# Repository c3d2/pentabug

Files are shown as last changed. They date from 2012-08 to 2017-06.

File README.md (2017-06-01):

pentabug
========

**If you experience difficulties with your bug, please check the [troubleshooting documentation](https://github.com/c3d2/pentabug/blob/master/troubleshooting.md).**

The pentabug is a small microcontroller soldering project. It's especially suited for young hackers and beginners of all ages. Assembly requires no prior soldering skills and can be accomplished - with a little help for the tricky parts - by children old enough to savely hold a soldering iron (thats about 7 years and up).

At various events, e.g. [Datenspuren 2012 and 2013](http://datenspuren.de "Datenspuren 2012 and 2013"), Chaos Communication Congress 2012-2015, and many more, several hundred kits have been successfully assembled with just a handfull of bugs needing 'special treatment' for e.g. a controller mounted the wrong way. Have a look at our [slides in german](/c3d2/pentabug/raw/master/doc/201210_slides_datenspuren.pdf "slides form the Datenspuren 2012 talk") from the accompanying [presentation](http://www.datenspuren.de/2012/fahrplan/events/5074.de.html "pentabug talk announcement") or watch [this video](http://www.youtube.com/watch?v=HTBhXqNR6LY "Dresdner Piratencast Folge 14 - Datenspuren") of Frank and his sons beeing interviewed at our workshop table or the [NDR report](https://www.ndr.de/fernsehen/sendungen/hamburg_journal/Kleine-Hacker-am-Werk,hamj45298.html) covering the 32c3 Junghackertag.

A complete walktrough of the assembly process is given in ["Pentabug - The Movie"](http://www.c3d2.de/news/video-pentabug-bauen.html "Pentabug - The Movie"), courtesy of [C3D2 - Chaos Computer Club Dresden](http://c3d2.de "C3D2 - Chaos Computer Club Dresden"). It would be amazing if Scott Manley could do an english version ;-). I would even visit SF to make that happen. 

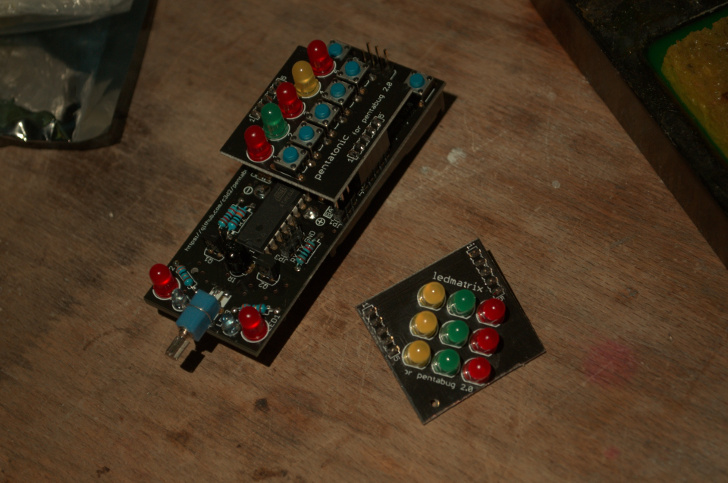
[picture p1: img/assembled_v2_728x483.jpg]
Assembled V2 PCB with extension boards
  
Img. 1: A completely assembled V2 PCB with extension boards.

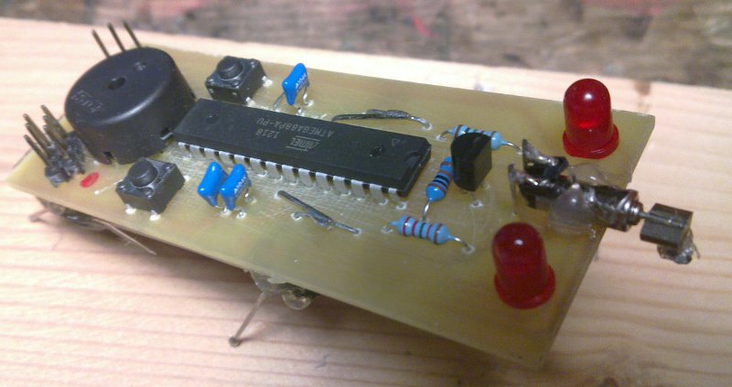
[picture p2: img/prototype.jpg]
Slightly Advanced Prototype Hardware
  
Img. 2: A slightly advanced (but early) prototype version of the bug with a single layer pcb.

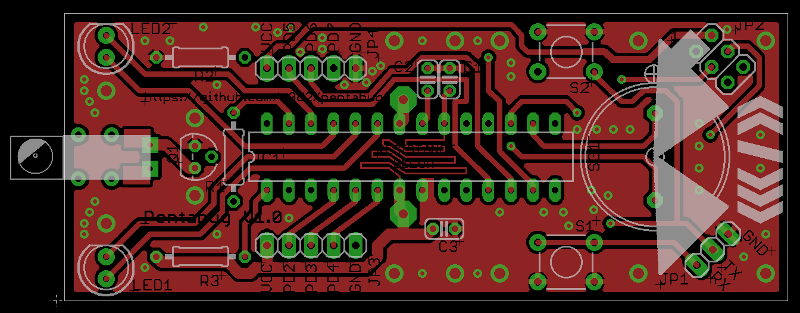
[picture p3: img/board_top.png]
Top Layer of Version 1.0 Board
  
Img. 3: The top layer view of the Version 1.0 production board (two layer pcb).

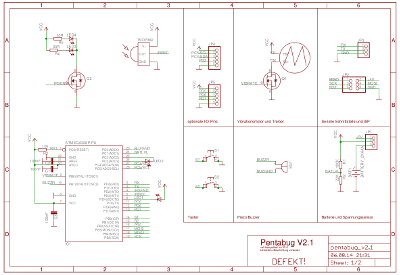
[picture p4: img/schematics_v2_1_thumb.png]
Version 2.1 Schematics (Thumbnail)
  
Img. 4: Version 2.1 schematics ([high resolution image](https://github.com/c3d2/pentabug/raw/master/img/schematics_v2_1.png "high resolution image of schematics")).

[Bill of Materials for Version 1.0](https://github.com/c3d2/pentabug/blob/master/bom.md "bill of materials") - CAVE: This is outdated for the V2.0 and V2.1 versions.

Programming
===========

A quite comprehensive documentation in German for setting up the development toolchain is available at [RHOIO's Blog](https://rhoio.wordpress.com/2014/02/06/den-pentabug-programmieren/).

AVR GCC Toolchain
------------------

 * install binutils-avr, gcc-avr, avr-libc, avrdude
 <pre><code>sudo apt-get install binutils-avr gcc-avr avr-libc avrdude</code></pre>

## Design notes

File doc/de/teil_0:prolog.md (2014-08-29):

# RTFM: Pentabug

## Vorwort

Lieber Junghacker-Padawan,

dies ist die Dokumentation zum [Pentabug-Projekt](https://github.com/c3d2/pentabug).

Wenn Du sie liest und verinnerlichst, wirst Du Deinen Pentabug von innen bis
aussen kennen. Du wirst wissen, wie er entstanden ist, wie er aufgebaut ist,
welche Fähigkeiten er besitzt und wie Du ihn erweitern kannst.

Doch viel mehr wirst Du selbst gelernt haben, ein Projekt wie den Pentabug zu
realisieren. Du wirst zum Junghacker-Jedi.

## Struktur dieser Dokumentation

Diese Dokumentation ist in verschiedene Teile aufgebaut.
Wir fangen ganz von vorne an und gehen bis ganz zum Ende. 
Danach gehen wir noch weiter nach vorne und enden noch weiter hinten.

So kommst Du ganz ohne Basiswissen schnell zu ergebnissen und brauchst nur
jeweils so viel lesen, wie Dich interessiert.

Teil 1: [Episode 2 - Das Gelöt von Pentabug](teil_1:episode_2.md)  
Teil 2: Episode 3 - Mögen die Bits mit Dir sein  
Teil 3: Episode 1 - Layout und Ätzen  

# Teil 1: [Episode 2 - Das Gelöt von Pentabug](teil_1:episode_2.md)  

Inhalt soll werden: 
 - Funktionen des Pentabug 
 - Wie findet man den richtigen Lötkolben
 - Wie lötet man richtig.
 - Was machtjedes Bauteil

# Teil 2: Episode 3 - Mögen die Bits mit Dir sein  TODO
# Teil 3: Episode 1 - Layout und Ätzen TODO

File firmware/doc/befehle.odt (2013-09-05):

#include <pentabug/hal.h>

led_on(seite) | Macht die LED auf einer Seite an
led_off(seite) | Macht die LED auf einer Seite aus
led_inv(seite) | Wechselt ob LED an oder aus ist
led_set(seite, an) | Macht LED aus wenn zweiter Parameter 0 ist, sonst an
led_state(seite) | Gibt zurück ob LED an ist
motor_on() | Macht Motor an
motor_off() | Macht Motor aus
motor_inv() | Wechselt ob Motor an oder aus ist
motor_set() | Macht Motor aus wenn Parameter 0 ist, sonst an
button_clicked(seite) | Gibt zurück ob der Button gedrückt wurde
ir_on() | Sendet Infrarot Signal
ir_off() | Schaltet Infrarot Signal aus
ir_inv() | Wechselt ob Infrarot Signal gesendet wird
ir_set() | Macht IR Signal aus wenn 0, sonst sendet es
ir_recv() | Gibt 1 zurück wenn Signal empfangen wird, sonst 0
wait_ms(ms) | Wartet die gegebene Anzahl an Millisekunden (kleiner als 1.5s!)

#include <pentabug/music.h>

set_note(note, oktave) | Spielt den entsprechenden Ton
stop_note() | Stoppt die Wiedergabe von Tönen

#include <pentabug/photons.h>

photons_init() | Initialisiert Lichtmessung
photons_stop() | Stoppt die Lichtmessung
photons_measure() | Gibt zurück wieviel Licht gemessen wurde (0-256)

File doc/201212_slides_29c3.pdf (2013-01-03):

pentabug | pentarm13uxx | outtro

## pentabug and pentarm13uxx

unadulterated fun with microcontrollers (for everyone)

bigalex, sebseb7

pentabug - beep. rattle. narf.

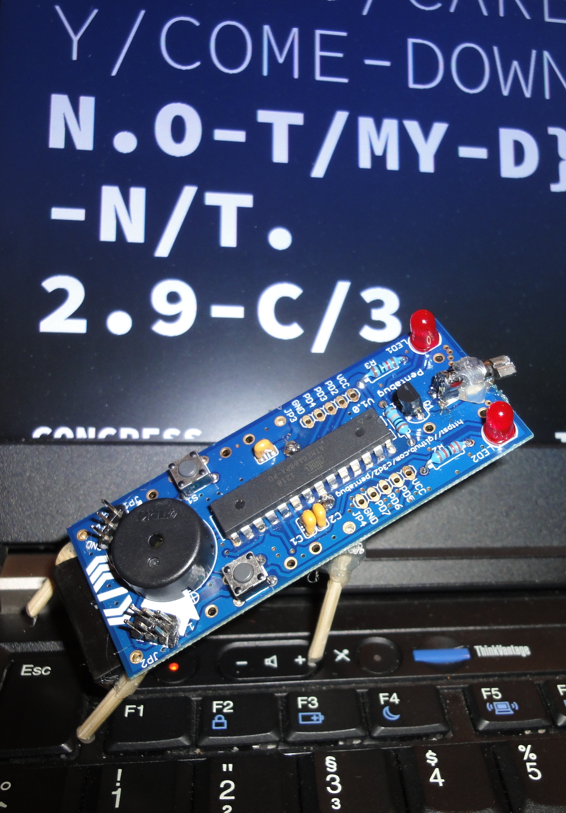
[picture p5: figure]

I battery powered ATmega88P I LEDs, switches
I piezo buzzer, vibration motor I ISP, USART
I extension connectors
I entry level project for beginners
I 100 bugs built at Datenspuren 2012

## Being n1ce to novices

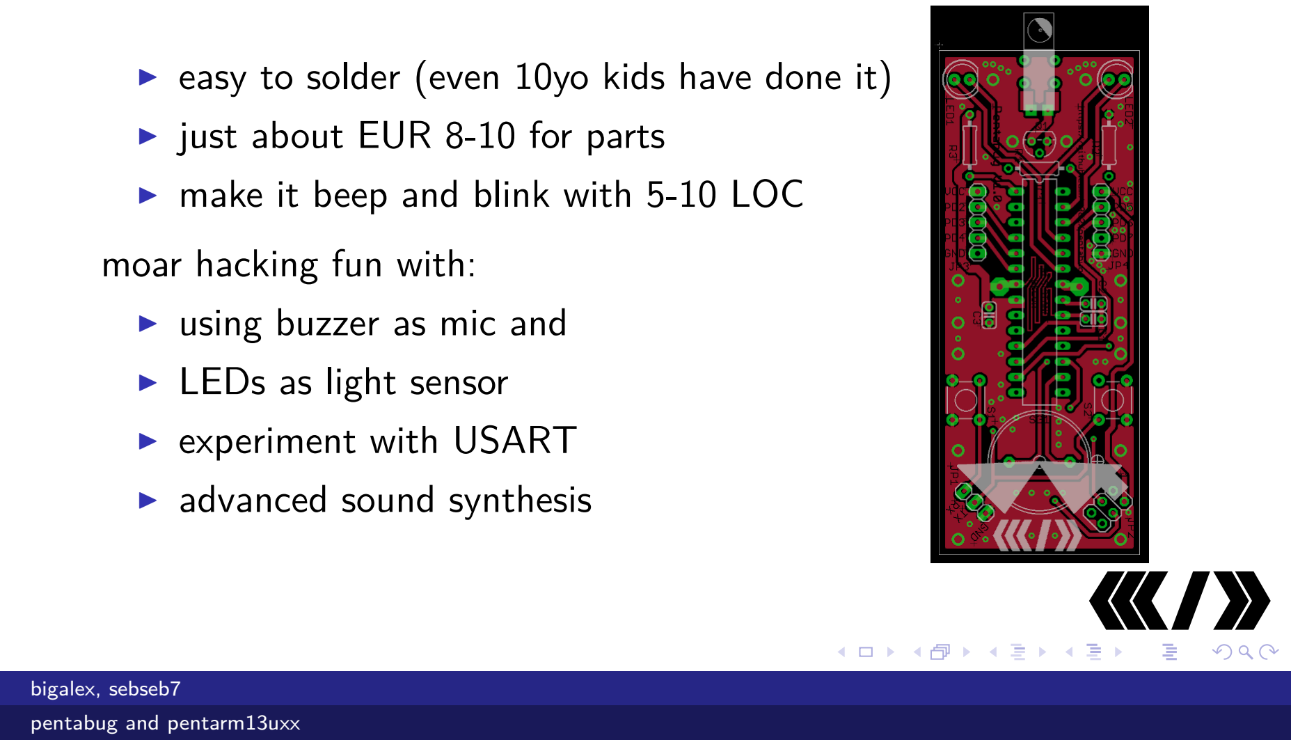
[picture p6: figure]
I just about EUR 8-10 for parts I make it beep and blink with 5-10 LOC moar hacking fun with: I using buzzer as mic and I LEDs as light sensor I experiment with USART I advanced sound synthesis

I easy to solder (even 10yo kids have done it)

## pentarm13uxx - small ARM development board

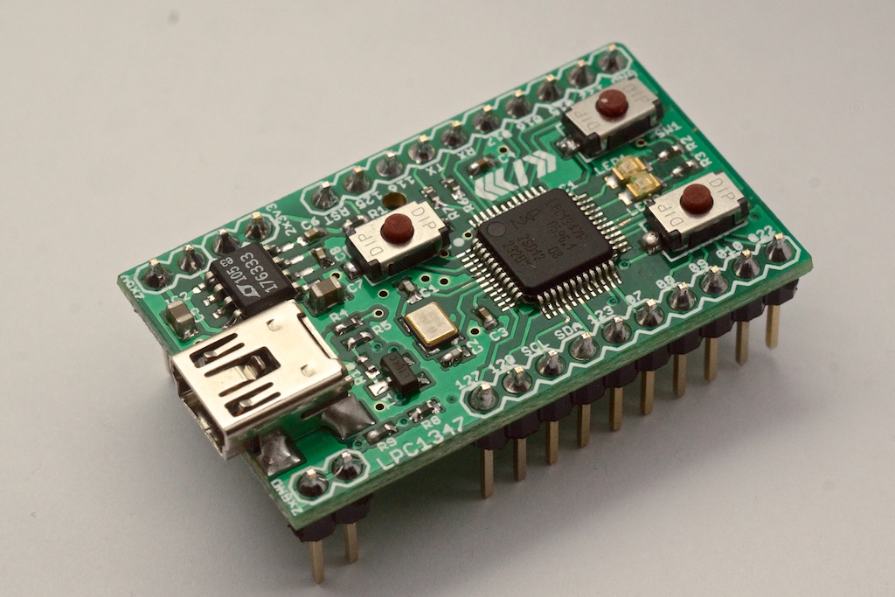
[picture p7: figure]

when you crave for more:
I template project for NXP LPC1347 (32-bit ARM Cortex-M3)
I intermediate SMD soldering skills
I some 0402 components
I getting started with ARM development

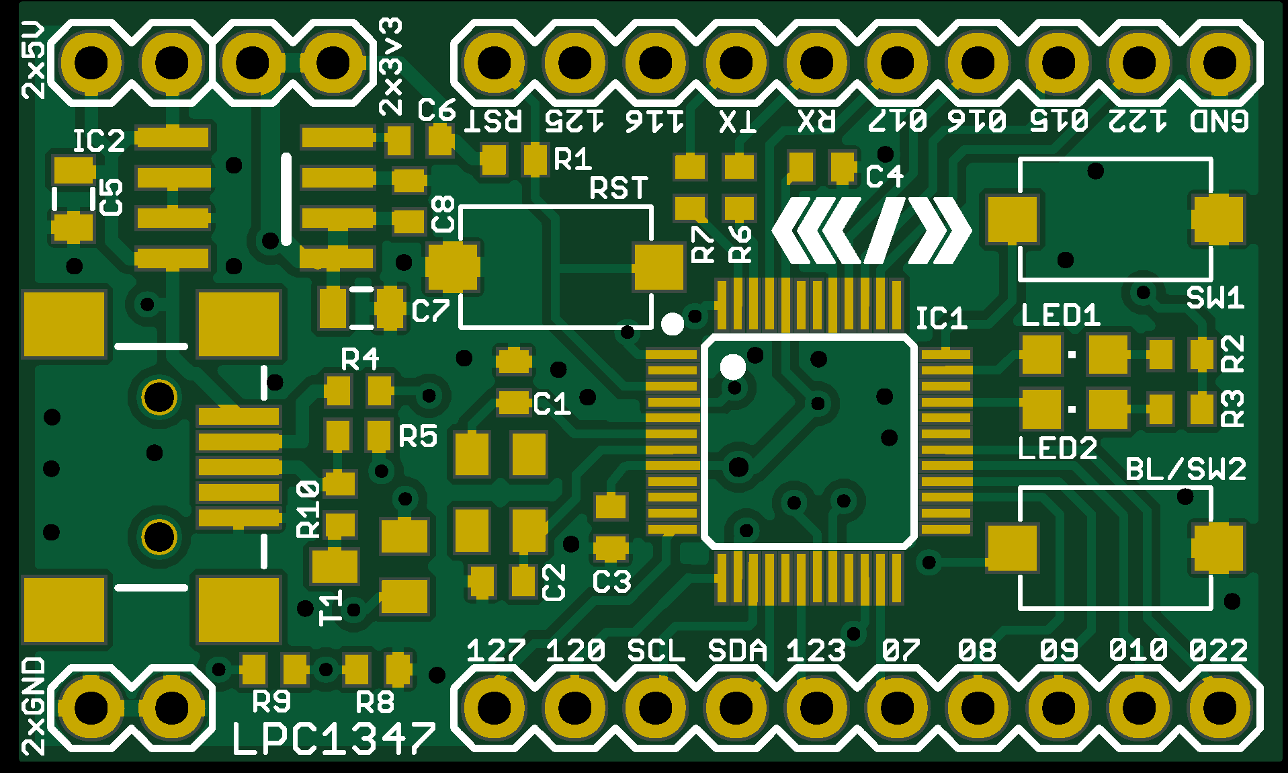
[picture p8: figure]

## Thank you for listening! Questions?

## Please meet us at the C3D2 table at the hardware

hacking area or at our workshops.

http://events.ccc.de/congress/2012/wiki/Pentabughttp://events.ccc.de/congress/2012/wiki/Pentarm13uxx

Many THX to 2bt, _john and thammi.

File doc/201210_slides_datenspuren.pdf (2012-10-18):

Motivation | Hardware | Software | Didaktische Aspekte | Demonstration | Zusammenfassung

## pentabug

beep, rattl, narf

2bt, bigalex, _john

Oktober 2012

Motivation

Hardware

Software

Didaktische Aspekte

Demonstration

## What the Bug!

I Because we can and thought it’s fun. I Interessantes und günstiges Projekt für den Junghackertrack.
I Nutzung für CMS.
I Einfacher, spielerischer Einstieg in uC-Technik (Hard- und Software). I Soll Spaß machen und viele

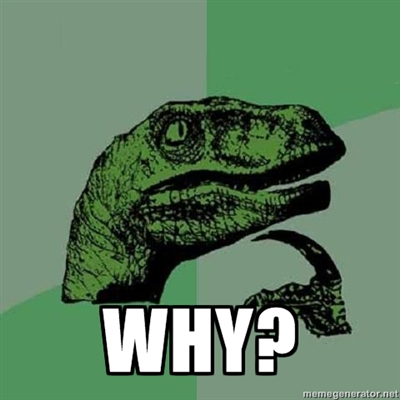
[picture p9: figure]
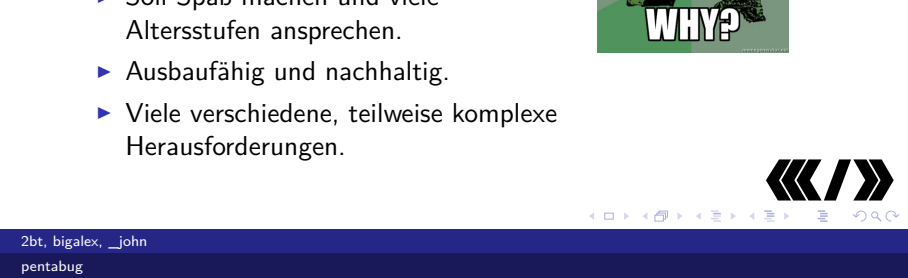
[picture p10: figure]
Altersstufen ansprechen. I Ausbaufähig und nachhaltig. I Viele verschiedene, teilweise komplexe Herausforderungen.

## Prozessor: ATMEL ATmega88P

I Preiswert (1,20 EUR), weit verbreitet, einfach zu programmieren.
I Viele Beispiele und Tutorials im Netz. I Nur wenige Peripheriekomponenten notwendig.
I PDIP 28 - Gehäuse, leicht zu löten. I 8-bit AVR RISC
I 8KB flash, 512B EEPROM, 1KB SRAM
I 23 GPIO, 3 CTC, USART

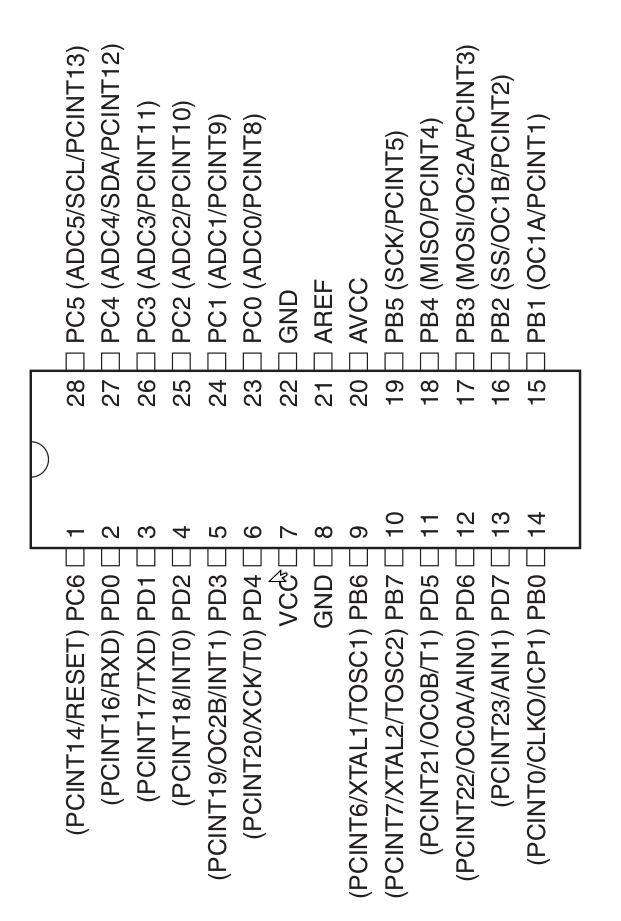
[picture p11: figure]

## LED und Schalter

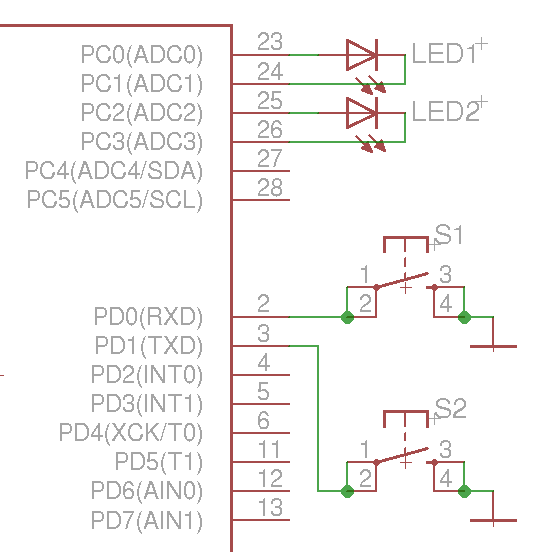
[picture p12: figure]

I Low Current LEDs
I Kein Vorwiderstand notwendig. I An ADC-Pins für
Helligkeitsmessung.
I Taster gegen GND (nutzen interne Pull-Ups).

## Motor

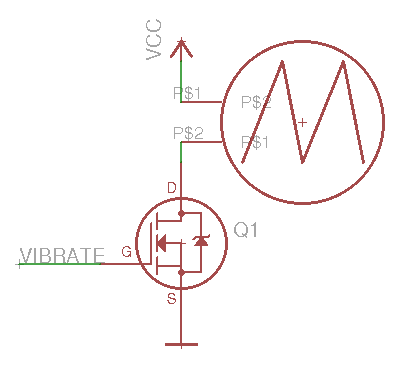
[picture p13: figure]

I Vibrationsmotor für
Mobiltelefone.
I 2N7000 N-Kanal FET
I Kein Vorwiderstand notwendig. I Bis 400mA
I Interne Freilaufdiode.
I Robust (ESD!) und preiswert.

## Mechanischer Aufbau

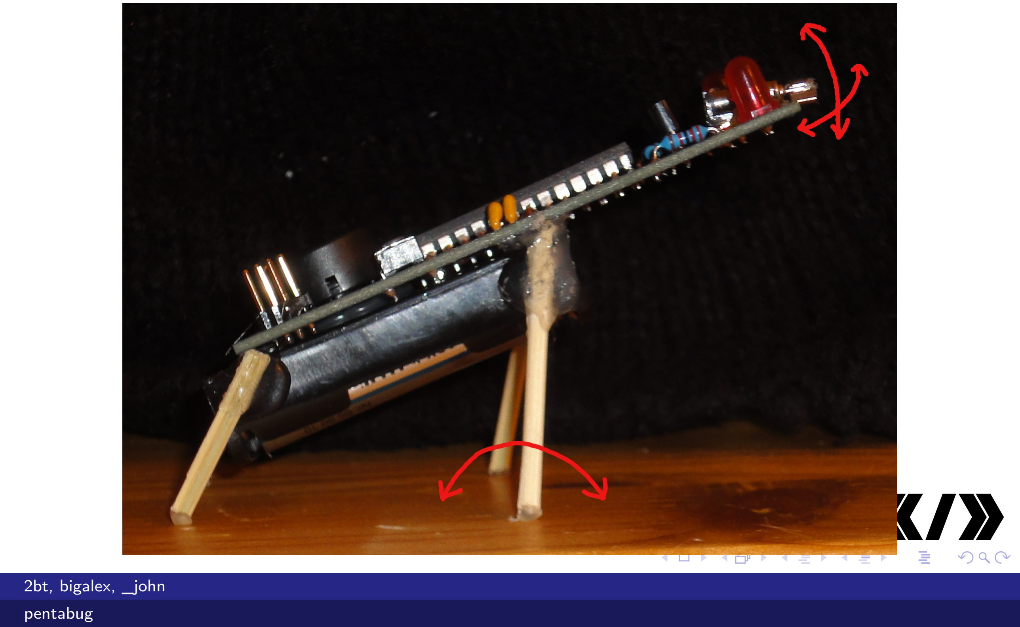
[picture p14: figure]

## Piezo-Buzzer

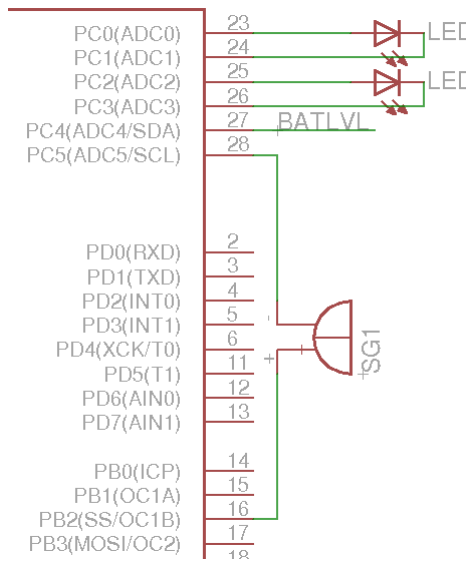
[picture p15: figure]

I Anschluss an zwei Pins (nicht gegen GND)
I Größerer Schallpegel
I Als Schallsensor verwendbar (ADC-PIN)
I unerwartet großer
Ladungsspeicher

## Sonstiges

I Programmierschnittstelle ISP
I Programmieren per USART (erfordert Bootloader)
I Bidirektionale Kommunikation per USART (Debugging, Meßwerte auslesen, ...)
I Spannungsteiler zum Messen von Vcc an ADC-Pin
I 6 Ports + Vcc + GND auf Lötpunkten für Stift-/Buchsenleisten

## Programmerzeugung in C (GNU Toolchain)

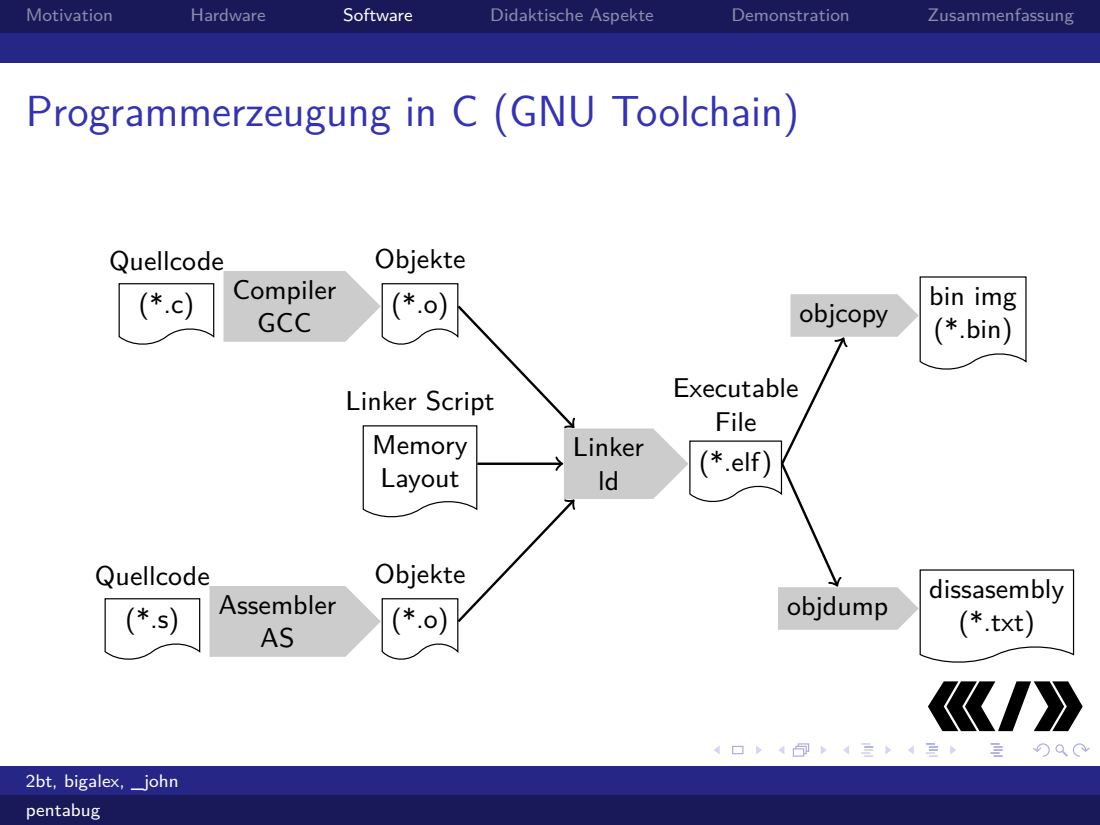
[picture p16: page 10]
(*.elf); Executable File; Linker ld; Memory Layout; Linker Script; Objekte; Objekte (*.o) Assembler AS; Compiler GCC (*.c); Quellcode; bin img (*.bin); dissasembly (*.txt); objcopy; objdump

## Beispielcode

## Minimalbeispiele

## Led, Motor ansteuern:

1 | /* Leds als Ausgang konfigurieren: */
2 | DDRC |= (1 << PORTC0) | (1 << PORTC1) |
3 | (1 << PORTC2) | (1 << PORTC3);
4 | while (1){/* endlosschleife */
5 | /* Leds ausschalten: */
6 | PORTC &= ~( (1 << PORTC0) | (1 << PORTC1) |
7 | (1 << PORTC2) | (1 << PORTC3) );
8 | /* Sekunde warten:*/
9 | _delay_ms(1000);

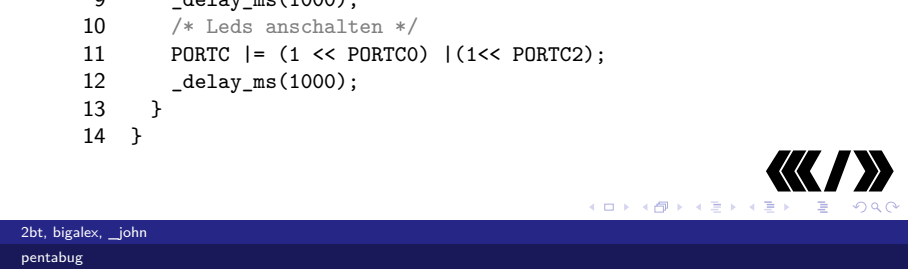
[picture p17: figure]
/* Leds anschalten */; _delay_ms(1000);

11 | PORTC |= (1 << PORTC0) |(1<< PORTC2);

## einfache Tonerzeugung

## ist wie schnelles Blinken

1 | /* Piezo als Output */
2 | DDRC |= (1 << PORTC5);
3 | DDRB |= (1 << PORTB2);
4 | buzzr_off();
5
6 | /*endlos */
7 | while (1){
8 | buzzr_up();

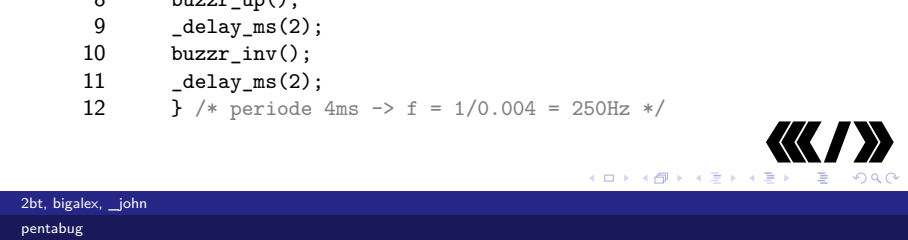
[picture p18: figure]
_delay_ms(2);; buzzr_inv();

12 | } /* periode 4ms -> f = 1/0.004 = 250Hz */

## einfaches Tasten abfragen

Der Pinzustand steht im PIN Register
1 {
2 | /* Leds als Ausgang konfigurieren: */
3 | DDRC |= (1 << PORTC0) | (1 << PORTC1) |
4 | (1 << PORTC2) | (1 << PORTC3);
5 | /* Taster als Eingang */
6 | DDRD &= ~((1<<PORTD0)|(1<<PORTD1));
7 | /* pullup an */
8 | PORTD |= (1<<PORTD0)|(1<<PORTD1);
9 | while (1){
10 | /* Leds ausschalten: */
11 | PORTC &= ~((1 << PORTC0) | (1 << PORTC1) |
12 | (1 << PORTC2) | (1 << PORTC3) );
14 | while (!(PIND & 0b00000011)) { /*nichts*/ }

## uart als debugterminal

… wenn geblinke nicht mehr ausreicht

## uart als debugterminal

Analogwandlerwerte auslesen:
1 | while(1){
2 | /* neuen wert lesen: */
3 | analogwert = ADCW;
4 | /* wert auf serieller schnittstelle ausgeben: */
5 | USART0_put_uint16(analogwert);
6 | USART0_crlf(); //neue zeile...
7 | }

## Schallsensor

## Der Piepslautsprecher funktioniert auch „falsch“ herum!

## Led als Lichtsesor

Eine Led ist auf verschiedene Weisen als Lichtsensor zu gebrauchen:
I Sperrschichtkapazität aufladen, Fotostrom entlädt
I LED als „Solarzelle“

## Level 1: Löten,Aufbau,kreative Bastelei

I Do something different and do it yourself !
I Kinder (und Erwachsene) für Technik begeistern.
I Man kan Dinge selber gestalten statt Vorgefertigtes zu verwenden.
I Erfolgserlebnisse mit niedriger Einstiegshürde.

## Level 2: Computer in elektronischen Geräten

I Jeder ist von ständig von vielen(!) Computern umgeben.
I Irgendjemand bestimmt, was diese tun und wie sie etwas tun. I Man kann damit viele Dinge tun, mit denen man nicht rechnet.

## Level 3: Code selbst verstehen und gestalten

I Verstehen und nachvollziehen was Programme tun. I Software/Hardware anpassen und ändern.
I Eigene kreative Ideen praktisch umsetzen.
I Code mit anderen teilen und gemeinsam entwicklen.

## Showcase

I Komplexerer Code, der zeigt, was mit wenig Hardware alles möglich ist.
I Polyphoner Synthesizer
I Lichttheremin
I Schreckbug

I Pentabug als einsteigergeeignetes uC-Projekt. I Preiswert und einfach aufzubauen.
I Schnelle Erfolge für Einsteiger.
I Anspruchsvollere “Hacks” für Fortgeschrittene.
I Erweiterbar, z. B. für Projekte nutzbar.
I Gute Resonanz bei Junghackern und Jugendlichen I Sa: 40 Bausätze, nahezu alle fehlerfrei aufgebaut.

## Danke fürs Zuhören! Fragen?

Literatur

C3D2 auf github.
URL: http://github.com/c3d2/pentabug. Mikrocontroller AVR-GCC-Tutorial.
URL: http://www.mikrocontroller.net/articles/AVR-GCC-Tutorial. (http://www.mikrocontroller.net/articles/AVR-GCC-Tutorial)
Mikrocontroller AVR-Tutorial.
URL: http:
//www.mikrocontroller.net/articles/AVR-Tutorial.

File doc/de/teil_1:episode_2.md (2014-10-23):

# Das Gelöt von Pentabug

In dieser Episode erfährst Du, junger Padawan, was Dein Pentabug so kann, wie
Du ihn zusammenbaust und dann zum Leben erweckst.

## Was kann son Pentabug eigentlich?

Der Pentabug ist ein kleiner Roboter, den Du selbst zusammebauen und
programmieren kannst.  Er ist recht einfach gehalten und gerade für Einsteiger
im Bereich der Elektronik besonders gut geeignet.

Der Pentabug kann leuchten, piepen, sich bewegen, auf Geräusche reagieren,
Infrarot senden und empfangen. Das kann man zum einen dafür nutzen, dass sich
verschiedene Pentabugs unterhalten, zum anderen aber auch um Geräte
fernzusteuern. Zudem ist er erweiterbar, d.h. man kann recht einfach weitere
kleine Schaltungen bauen, die seine Funktionen erweitern.

## Voraussetzungen

Wenn Du einen Pentabug bauen möchtest benötigst Du neben einem Pentabug-Bausatz folgende weitere Dinge:

1. 1 Lötkolben
2. 1 Schwämmchen, feucht. Ein feuchtes Tuch tut es auch.
3. Lötzinn.
4. 1 hitzebeständige Arbeitsunterlage (z.B. kleines Holzbrett oder eine Pappe).
5. 1 Heißklebepistole mit Kleber
6. 1 Seitenschneider
7. 1 Spitzzange (nicht unbedingt zwingend)

Für den Fall, dass Du mal fehler machst, benötigst Du weitere Dinge:

8. 1 Multimeter
9. 1 Lötlutsche und / oder Entlötlitze

### Auswahl des Lötkolbens und des Lötzinns

Der Lötkolben ist ein Werkzeug mit dem man die verschiedenen elektornischen
Bauelemente mit einander verbindet. Er wird mit Strom betrieben und wird sehr
heiß.  Diese Hitze nutzt man um Lötzinn zum schmelzen zu bringen, welches dann
sozusagen die elektrischen Bauelemente elektrisch leitend mit einander
verklebt.

Wenn Du noch keinen Lötkolben zur Verfügung hast, also jetzt loslaufen möchtest
um Dir einen zu besorgen, achte darauf, dass er mindestens 25 Watt hat. Wenn er
mehr Watt hat, macht das Löten allerdings mehr Spass, da man pro Lötstelle
nicht so lange auf das Heißwerden warten muss.

Die Spitze sollte nicht zu dick sein; einen Feinlötkolben benötigst Du für
dieses Projekt allerdings auch nicht.

Überlege, ob Du gleich eine kleine Lötstation kaufst. Die hat meistens gleich
einen Halter für den Kolben, ein kleines Schwämmchen dabei und man kann die
Leistung des Lötkolbens regeln.

Ein Beispiel für einen ausreichendes Lötgeröt findet Ihr
[hier](http://www.amazon.de/dp/B000UNM0QY/). [Disclaimer] Da ist auch schon gleich eine
Lötlutsche dabei.

Wenn Ihr nicht gleich einen Lötkolben kaufen wollt, könnt Ihr ihn bestimmt in
einem [Hackerspace](http://hackerspaces.org) in Eurer Nähe ausleihen, um den
PBG zu bauen.

TODO: kann wer was zum Zinn schreiben?

TODO: Da man bei den ganzen Sachen hier immer wieder was besorgen muss sollten
wir auch Tips zum besorgen der Werkzeuge und Elemente geben. 

### Auswahl des Multimeters

Das Multimeter ist ein Werkzeug mit dem man verschiedene (deswegen "multi")
elektrische Messgrößen erfassen (d.h. messen, deswegen
["meter"](http://de.wikipedia.org/wiki/Meter)) kann.

Für den Pentabug reicht ein ganz billiges aus dem Baumarkt oder halt auch von
[Amazon](http://www.amazon.de/dp/B003IP80SS/).

## Die Bauteile erklärt

Damit Ihr wisst, was Ihr verbaut, folgt hier noch eine kurze Erklärung der einzelnen Bauteile.
Die Erklärung folgt ist nicht unbedingt die Reihenfolge in der Ihr die Bauteile auch später verbaut.

### Die Platine

TODO: Insert hier Bild von PLatine

Die Platine ist das Bauteil, auf der alle anderen Bauteile befestigt werden. Sie hat für jedes benötigte Bauteil vorgefertigte Löcher / Bohrungen, sowie Beschriftungen. Zusätzlich liegen auf ihr unter dem Lack Kupferleitungen zwischen einigen Löchern. Diese Kupferleitungen sind wie Kabel und dienen dazu, später den Strom zu transportieren.

### Die Batterie

TODO: Insert hier Bild von Batterie

Eine Batterie kennt Ihr. 

Sie liefert die benötigte Energie um den Pentabug später zu betreiben. Neben der richtigen Form und Größe gibt es noch weitere wichtige Eigenschaften einer Batterie, die ein Jedi kennen muss: 

Eine Batterie hat immer zwei Pole ("+" und "-"). Im inneren dieser Batterie befinden sich an einem Polende viele Elektronen, die gerne an das andere Polende kommen möchten. Da es im inneren der Batterie aber keinen Durchgang gibt, können die Elektronen nur außen herum, wenn man ihnen eine Möglichkeit dazu gibt. Den Weg, den der Pentabug den Elektronen der Batterie bietet, ist der eigentliche Schaltkreis. Die Elektronen werden also von dem einen Pol der Batterie durch die Schaltung des Pentabug, durch alle Bauteile hindurch, zum anderen Pol der Batterie geleitet. Ein bestimmtes, weiter unten besprochenes, Bauteil verhindert, dass die Elektronen immer durch alle Bauteile fließen, sondern nur dann, wenn der Padawan dies wünscht.

Den Wunsch, wie dolle die Elektronen von einem Pol zum anderen wollen, nennt man *Spannung*. Diese Spannung wird in der Einheit *Volt* (V) angegeben. Auf der Batterie ist aufgedruckt, welche Spannung sie liefert. Die Bauteile stellen eine gewisse Hürde auf um überquert zu werden. Diese Hürde nennt man *Widerstand*. Er wird in der Einheit *Ohm* (Ω) angegeben. Dann wäre da noch der Begriff des *Strom*es. Dieser beschreibt (zumindest ungefähr) wie viele Elektronen an einer gewissen Stelle durchfließen. 

TODO: URI jetzt noch im Zusammenhang erklären und paar Beispiele geben. Vielleicht auch noch eine weniger abstrakte Beschreibung liefern?

## Auf gehts

Jetzt geht es schon ans Zusammenbauen des Pentabugs. Wenn Du kein Bock auf
lesen hast, haben wir dafür auch ein
[Video](http://c3d2.de/news/video-pentabug-bauen.html) vorbereitet, was gut
erklärt, wie der Pentabug gelötet wird.

Während Du jetzt also das Lichtschwert eines jeden Junghackers, also den
Lötkolben an der Steckdose heiß werden lässt, packe die einzelnen Bauteile des
Pentabug vor Dir aus und schaue sie genau an. Am besten sortierst Du sie, damit
Du sie schnell griffbereit hast.

In der PBG-Kiste ist auch ein Zettel, der die nötigsten Informationen
zusammenfasst. Bei einigen Bauteilen muss man aufpassen, in welcher Richtung
man sie einbaut.

Die Bauteile werden in der Reihenfolge verbaut, in der sie auf dem Zettel
stehen. Das macht man deswegen, weil man später an manche Bauteile nicht mehr
so gut rankommt, wenn rundherum schon viele andere Teile verbaut sind.

Das Basis-Bauelement, auf dem alle anderen Teile verbaut werden, ist die
Platine.

### Wie man richtig lötet

[Disclaimer]: Auch andere Läden haben Lötkolben oder andere Werkzeuge / Bauelementeund die von uns angegebenen Links sind keinesfalls die besten oder billigsten Teile. Die Links sollen Euch lediglich in die ungefähre Richtung schicken.

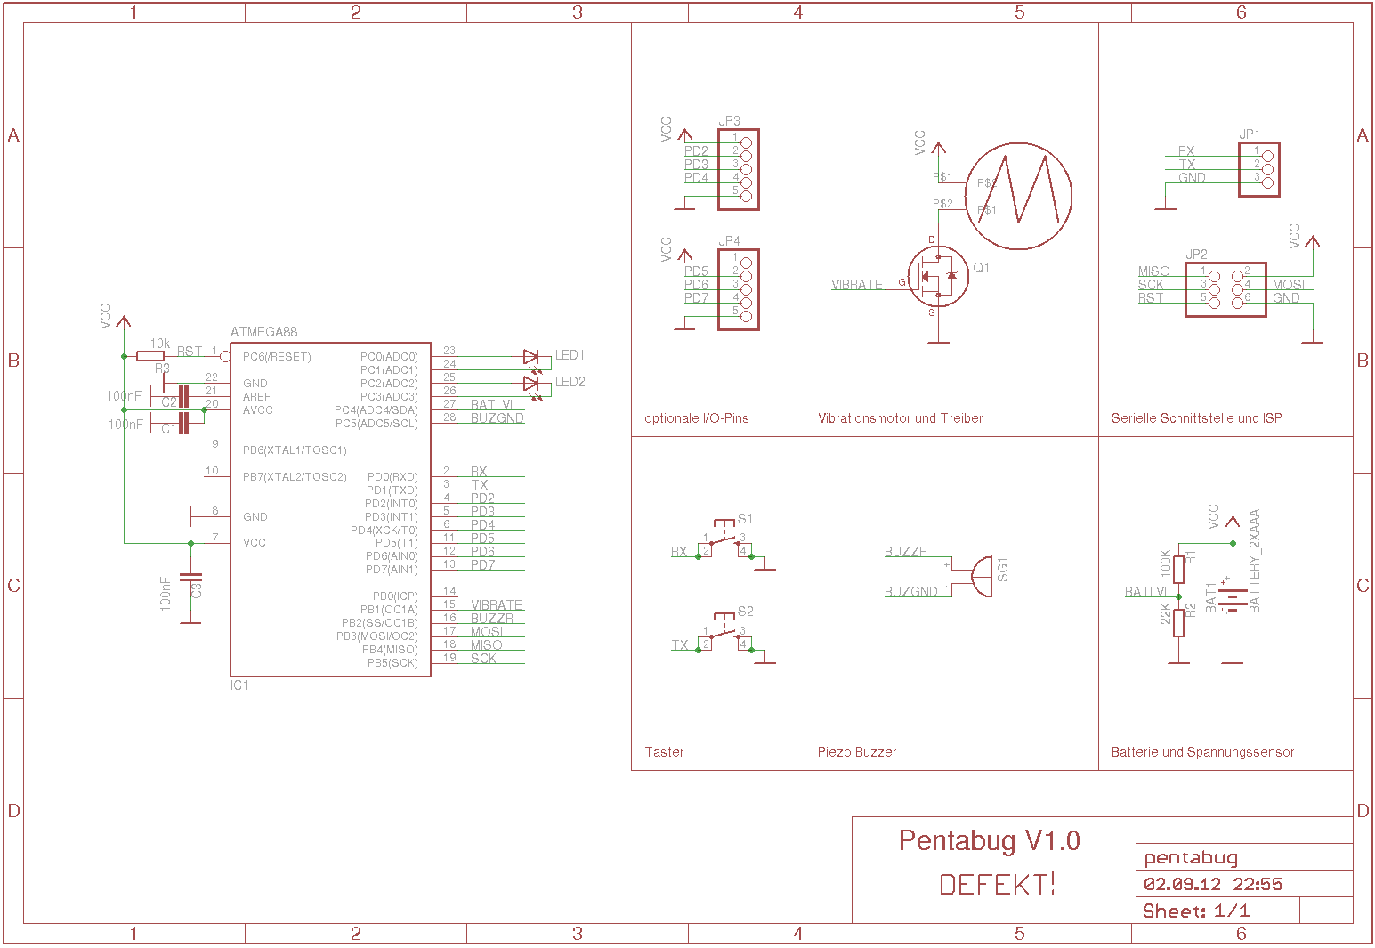
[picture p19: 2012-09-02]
img/schematics_v1_0.png

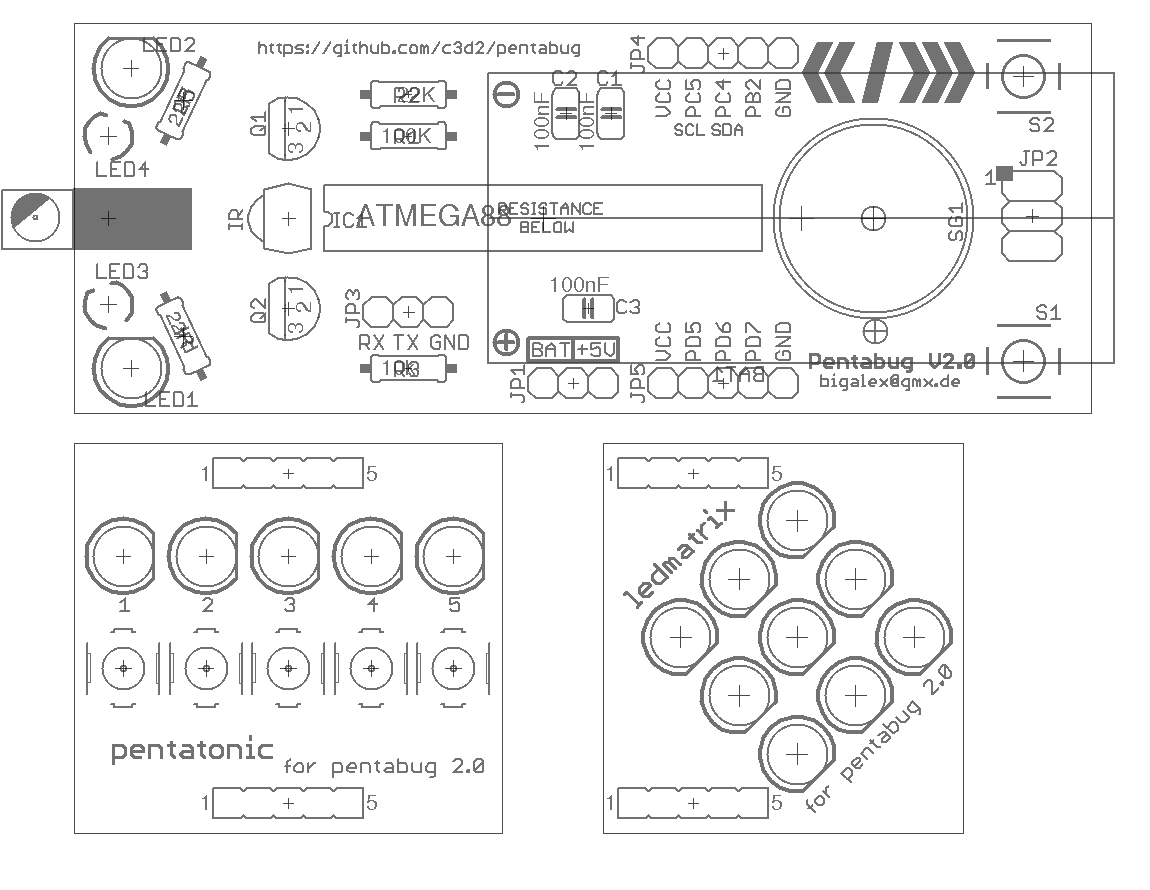
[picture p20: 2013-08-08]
hardware/v2/bestueckung.png

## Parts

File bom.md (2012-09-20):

# Parts List

<table>
<tr><th>Bezeichnung	</th><th>Bauteil</th><th>Hinweis</th></tr>
<tr><td>n/a		</td><td>Leiterplatte V1.0		</td><td></td><tr>
<tr><td>IC1		</td><td>Mikrocontroller ATMEGA88PA	</td><td>Einbaulage beachten</td><tr>
<tr><td>R1		</td><td>Widerstand 100K		</td><td>braun-schwarz-schwarz-gelb-braun</td><tr>
<tr><td>R2		</td><td>Widerstand 22K			</td><td>rot-rot-scharz-rot-braun</td><tr>
<tr><td>R3		</td><td>Widerstand 10K			</td><td>braun-schwarz-schwarz-rot-braun</td><tr>
<tr><td>Q1		</td><td>Transistor 2N7000		</td><td>Einbaulage beachten</td><tr>
<tr><td>C1, C2, C3	</td><td>Keramikkondensator 100nF	</td><td></td><tr>
<tr><td>LED1, LED2	</td><td>LED rot			</td><td>Polarität beachten</td><tr>
<tr><td>SG1		</td><td>Piezo Buzzer			</td><td></td><tr>
<tr><td>JP1		</td><td>Stiftleiste 1x3		</td><td></td><tr>
<tr><td>JP2		</td><td>Stiftleiste 2x3		</td><td></td><tr>
<tr><td>S1, S2		</td><td>Taster				</td><td></td><tr>
<tr><td>M1		</td><td>Motor				</td><td></td><tr>
<tr><td>BAT1		</td><td>Batteriefach			</td><td>erst nach Test auf Platinenunterseite montieren</td><tr>
</table>

# cost calculation for 100 kits:

<pre><code>
name		description 	ben.Anzahl 	quelle/bestnr. 		einzelpreis(cent) 	summe(Euro)
---------	--------- 	----------- 	--------------  	----------------- 	--------------
IC1		ATMEGA88PA 	100 		mouser 			144 			144
BAT1		Batteriefach 	50 		hbc 			74 			~40
M1		motor(schwarz) 	100 		pollin 			125 			125
SG1		piezo buzzer	100 		mouser 			49			49
R1, R2, R3	widerst. 	300 		reichelt 		2.5 			7.50
Q1		2n7000 		100 		reichelt 		5 			5
C1, C2, C3	100nF 		300 		reichelt 		7 			21
JP1		head1x3 	100 		reichelt? 		7 			7
JP2		head2x3 	100 		reichelt? 		15 			15
LED1, LED2	ledSLH 56 	200 		reichelt 		7 			14
S1, S2		tacswitch	200		???			???			???
n/a		platine 	100 		mkpcb? 			150? 			~150
n/a		stahl.8mm 	25 		conrad 			50 			12.5
n/a		lötzinn 	1 		pollin 			795 			8
n/a		flyerA5 	100 		diekopie?  		3 			3
n/a		tüte 		100 		todo 			5 			5
n/a		glitzer 	100 		todo 			20 			20
n/a		glitter 	100 		todo 			20 			20
n/a		verbrauchsm     4  		dealer 			250 			10
n/a		aterial 	4 		dealer2 		250 			10
n/a		buzz variante   100 		reichelt 		10 			10
n/a		schmelzkleber 	1 		? 			1000 			10
n/a		sonstiges 	1 		dealer3 		115 			11.5
												summe:
											------------------------

------------------------------------------------------------------------------------------------

<code>										700
</pre>

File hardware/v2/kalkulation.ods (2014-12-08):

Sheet: Tabelle1
 |  |  | https://pentapad.hq.c3d2.de/p/bug-2013
 | platinen | 200 bugs 100 pentatonik 100 ledmatrix |  |  | 304,65
 |  | einfuhrumsatzsteuer |  |  | 54,837
 |  |  |  |  | 359,487 | 1,19829
platine bug | 1,2
platine pentatonik | 0,6
platine ledmatrix | 0,6
 |  |  |  |  |  |  |  |  | mouser | mouser 1st | mouser 100st | Reichelt-nr |  | reichelt 1st | mouser+mwst | BESTPRICE | 5,7566566667
 |  |  |  | BAT1 | Batteriehalter 2xAAA |  | 1 | 12BH423-GR | http://de.mouser.com/ProductDetail/Eagle-Plastic-Devices/12BH423-GR/ | 0,691 | 0,41 |  |  |  | 0,4879 | 0,4879 | 0,4879 | MOU
 |  |  |  | Batterien | AAA |  | 2 |  | http://de.mouser.com/ProductDetail/Panasonic-Battery/LR6XWA-B/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 | 0,289 | 0,202 |  | http://www.reichelt.de/Alkalinebatterien/GPR-AL-40XAAA/3/index.html | 0,19875 | 0,24038 | 0,19875 | 0,3975 | REI | pollin ist nicht billiger, was john gesehen hat waren AA, keine AAA
 |  |  |  | IC1 | ATMEGA 88 |  | 1 | 556-ATMEGA88PA-PU | http://de.mouser.com/ProductDetail/Atmel/ATMEGA88PA-PU/ | 2,02 | 1,15 |  |  |  | 1,3685 | 1,3685 | 1,3685 | MOU
 |  |  |  | IR1 | TSOP382 | 940nm 38KHz | 1 | 782-TSOP38238SS1V | http://de.mouser.com/ProductDetail/Vishay/TSOP38238SS1V/ | 0,52 | 0,413 |  |  |  | 0,49147 | 0,49147 | 0,49147 | MOU
 |  |  |  | C1, C2, C3 | 100nF |  | 3 |  | http://de.mouser.com/ProductDetail/Vishay-BC-Components/K104K15X7RF53K2/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 | 0,083 | 0,036 | Z5U-2,5 100N | http://www.reichelt.de/Vielschicht-bedrahtet-Z5U-20-/Z5U-2-5-100N/3/index.html | 0,04 | 0,04284 | 0,04 | 0,12 | REI
 |  |  |  | JP1, JP3 | PINHD 1x3 |  | 2 |  | http://de.mouser.com/Connectors/Headers-Wire-Housings/_/N-ay0lo?Ns=Pricing|0 |  |  | SL 1X36G 2,54 | http://www.reichelt.de/Stiftleisten/SL-1X36G-2-54/3/index.html | 0,16 |  | 0,0133333333 | 0,0266666667 | s.u. | 36polig-reichelt
 |  |  |  | JP2 | PINHD 2x3 |  | 1 |  | http://de.mouser.com/ProductDetail/3M-Electronic-Solutions-Division/929836-01-03-RK/ | 0,198 | 0,165 | MPE 087-2-006 | http://www.reichelt.de/Stiftleisten/MPE-087-2-006/3/index.html | 0,15 |  | 0,15 | 0,15 | REI
 |  |  |  | JP4, JP5 | PINHD 1x5 | weibchen | 2 |  | http://de.mouser.com/ProductDetail/3M-Electronic-Solutions-Division/929870-01-05-RA/ | 0,661 | 0,47 | MPE 094-1-005 | http://www.reichelt.de/Buchsenleisten/MPE-094-1-005/3/index.html | 0,26 | 0,5593 | 0,26 | 0,52 | REI
 |  |  |  | LED1, LED2 | LED5mm |  | 2 |  |  |  | 0,046 |  |  |  | 0,05474 |  | 0,12 | s.u.
 |  |  |  | LED3, LED4 | LED3mm-IR |  | 2 |  | http://de.mouser.com/ProductDetail/Everlight/EL-IR204-H16-L10/ | 0,176 | 0,134 |  | http://www.reichelt.de/Fotodioden-etc-/SFH-487-2/3/index.html | 0,29 | 0,15946 | 0,15946 | 0,31892 | MOU | http://www.everlight.com/datasheets/IR204-A-datasheet_2_datasheet.pdf
 |  |  |  | Q1, Q2 | 2N7000_TO92 |  | 2 |  | http://de.mouser.com/ProductDetail/ON-Semiconductor/2N7000RLRAG/ | 0,15 | 0,087 |  | http://www.reichelt.de/2N-Transistoren/2N-7000/3//index.html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 | 0,05 |  |  | 0,1 | REI
 |  |  |  | R1 | 100K |  | 1 |  |  |  |  | METALL 100K | http://www.reichelt.de/1-4W-1-100-k-Ohm-976-k-Ohm/METALL-100K/3/index.html | 0,025 |  | 0,025 | 0,025 | REI
 |  |  |  | R2 | 22K |  | 1 |  |  |  |  | METALL 22,0K | http://www.reichelt.de/1-4W-1-10-0-k-Ohm-95-3-k-Ohm/METALL-22-0K/3/index.html | 0,025 |  | 0,025 | 0,025 | REI
 |  |  |  | R3 | 10K |  | 1 |  |  |  |  | METALL 10,0K | http://www.reichelt.de/1-4W-1-10-0-k-Ohm-95-3-k-Ohm/METALL-10-0K/3/index.html | 0,025 |  | 0,025 | 0,025 | REI
 |  |  |  | R4, R5 | 33R |  | 2 |  | http://de.mouser.com/ProductDetail/KOA-Speer/MF1-4DC30R0F/ | 0,05 | 0,033 | METALL 33,0 | http://www.reichelt.de/1-4W-1-10-0-Ohm-97-6-Ohm/METALL-33-0/3/index.html | 0,025 |  | 0,025 | 0,05 | REI
 |  |  |  | S1, S2 | TACSWITCH |  | 2 | 642-MJTP1230 (MJTP1230=PHAP33019 | http://de.mouser.com/ProductDetail/Apem/MJTP1230/?qs=sGAEpiMZZMsgGjVA3toVBBXi3RKSr1bKWt8e9G1JY2g%3d | 0,08 | 0,057 | TASTEr 3301 | http://www.reichelt.de/Vielschicht-bedrahtet-Z5U-20-/Z5U-2-5-100N/3/index.html?ACTION=3;ARTICLE=27892;SEARCH=TASTER%203301 | 0,19 | 0,06783 | 0,06783 | 0,13566 | MOU
 |  |  |  | SG1 | BUZZER |  | 1 | 810-PS1720P02 | http://de.mouser.com/ProductDetail/TDK/PS1720P02/ | 0,685 | 0,416 |  |  |  | 0,49504 | 0,49504 | 0,49504 | MOU
 |  |  |  | M | MOTOR |  | 1 | http://www.pollin.de/shop/dt/MzY1OTg2OTk-/Motoren/Gleichstrommotoren/Vibrationsmotor.html |  |  |  |  |  |  |  |  | 0,85 | POLLIN
 |  |  |  | Kurzschlussbrücke |  |  | 1 | 151-8003-E | http://de.mouser.com/ProductDetail/Kobiconn/151-8003-E/ | 0,125 | 0,086 | JUMPER 2,54 RT | http://www.reichelt.de/Stiftleisten/JUMPER-2-54-RT/3/index.html | 0,05 | 0,10234 | 0,05 | 0,05 | REI
 |  |  |  | LED5-9 | LED5mm |  | 5 |  |  |  |  |  |  |  |  | 0,06 | 0,3
 |  |  |  | S3-S7 | TACSWITCH |  | 5 |  |  |  |  |  |  |  |  | 0,06783 | 0,33915
 |  |  |  | SV4,SV5 | PINHD 1x5 F |  | 2 |  |  |  |  |  |  |  |  | 0,0222222222 | 0,0444444444
 |  |  |  |  |  |  |  |  |  |  |  |  |  |  |  |  | 0,3835944444
 |  |  |  | SV_5, SV_5 | PINHD 1x5 F |  | 2 |  |  |  |  |  |  |  |  | 0,0222222222 | 0,0444444444
 |  |  |  | LED10-18 | LED5mm |  | 9 |  |  |  |  |  |  |  |  | 0,06 | 0,54
 |  |  |  |  |  |  |  |  |  |  |  |  |  |  |  |  | 0,5844444444
 |  |  |  | Gartenzaun |  |  |  |  |  |  |  | SL 1X36G 2,54 | http://www.reichelt.de/Stiftleisten/SL-1X36G-2-54/3/index.html | 0,16 | 50
 |  |  |  | Antistatic-matten |  |  |  |  |  |  |  | ESD PE-MOS 300http://www.reichelt.de/ESD-Verpackungsmaterial/ESD-PE-MOS-300/3/index.html | http://www.reichelt.de/ESD-Verpackungsmaterial/ESD-PE-MOS-300/3/index.html | 1,45 | 2
 |  |  |  | Biegeplüsch |  | http://www.amazon.de/Chenilledraht-Pfeifenputzer-Kindergartenpackung-100-Stk/dp/B00472R884?s=kitchen
 |  |  |  | Wackelaugen |  | http://www.amazon.de/Wackelaugen-rund-7mm-100-St%C3%BCck/dp/B00203YJ34?s=kitchen
 |  |  |  | Wackelaugen |  | http://www.amazon.de/Hotfix-Farben-Strass-Strasssteine-Glitzersteine/dp/B00BZPQMII?s=toys
 |  |  |  | glitzersteine |  | http://www.amazon.de/Hotfix-Farben-Strass-Strasssteine-Glitzersteine/dp/B00BZPQMII?s=toys
 |  |  |  | mit applikator
 |  |  | Stifleiste 36 polig bei reichelt
 |  |  | http://www.reichelt.de/Stiftleisten/SL-1X36G-2-54/3/index.html
 |  |  | per bug: 6 | 600
 |  |  | Pentatonic 10 | 500
 |  |  | Ledmatrix 10 | 500
 |  |  |  | sum | 1600
 |  |  |  |  | 44,4444444444 | --> 50 Stck
 |  |  |  | LEDs MOUSER
 |  |  |  |  | http://de.mouser.com/ProductDetail/Kingbright/WP7113LGD/
 |  |  |  |  | http://de.mouser.com/ProductDetail/Kingbright/WP7113LYD/
 |  |  |  | JP1, JP3

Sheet: EINKAUFSLISTE
MOUSER
BAT1 | Batteriehalter 2xAAA | 100 | 12BH423-GR | http://de.mouser.com/ProductDetail/Eagle-Plastic-Devices/12BH423-GR/ | 0,41 | 41 |  |  | SUMME: | 1089,19
IC1 | ATMEGA 88 | 100 | 556-ATMEGA88PA-PU | http://de.mouser.com/ProductDetail/Atmel/ATMEGA88PA-PU/ | 1,15 | 115
IR1 | TSOP382 940nm 38KHz | 100 | 782-TSOP38238SS1V | http://de.mouser.com/ProductDetail/Vishay/TSOP38238SS1V/ | 0,413 | 41,3 |  |  | Platinen | 359,49
LED3, LED4 | LED3mm-IR | 200 | 638-IR204/H16/L10 | http://de.mouser.com/ProductDetail/Everlight/EL-IR204-H16-L10/ | 0,134 | 26,8 |  |  | MOUSER | 381,34
S1, S2 | TACSWITCH | 450 | 642-MJTP1230 (MJTP1230=PHAP33019 | http://de.mouser.com/ProductDetail/Apem/MJTP1230/?qs=sGAEpiMZZMsgGjVA3toVBBXi3RKSr1bKWt8e9G1JY2g%3d | 0,057 | 25,65 |  |  | RECIHELT | 146,85
SG1 | BUZZER | 100 | 810-PS1720P02 | http://de.mouser.com/ProductDetail/TDK/PS1720P02/ | 0,416 | 41,6 |  |  | POLLIN | 89,95
LED grün |  | 300 | 604-WP7113LGD | http://de.mouser.com/ProductDetail/Kingbright/WP7113LGD/ | 0,046 | 13,8 |  |  | Verpackung | 20,3
LED gelb |  | 300 | 604-WP7113LYD | http://de.mouser.com/ProductDetail/Kingbright/WP7113LYD/ | 0,051 | 15,3 |  |  | Deko | 41,49
 |  |  |  |  |  |  | MwSt |  | schmelzkleber | 49,77
 |  |  |  |  |  | 320,45 | 381,34
REICHELT
Batterien | AAA (40er Packs) | 3 | GPR AL 40XAAA | http://www.reichelt.de/Alkalinebatterien/GPR-AL-40XAAA/3/index.html | 7,95 | 23,85
C1, C2, C3 | 100nF | 300 | Z5U-2,5 100N | http://www.reichelt.de/Vielschicht-bedrahtet-Z5U-20-/Z5U-2-5-100N/3/index.html | 0,04 | 12
JP2 | PINHD 2x3 | 100 | MPE 087-2-006 | http://www.reichelt.de/Stiftleisten/MPE-087-2-006/3/index.html | 0,15 | 15 |  |  |  |  |  | Einzelbestellung |  | Bestellung > 100
JP4, JP5 | PINHD 1x5 Fem | 200 | MPE 094-1-005 | http://www.reichelt.de/Buchsenleisten/MPE-094-1-005/3/index.html | 0,26 | 52 |  |  |  |  |  | pro Stück | gesamt | pro Stück | gesamt
Q1, Q2 | 2N7000_TO92 | 200 | 2N 7000 | http://www.reichelt.de/2N-Transistoren/2N-7000/3//index.html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 | 0,05 | 10 |  |  |  | 1 | Prozessor ATMEGA88PA | 2,40 | 2,40 | 1,37 | 1,37
R1 | 100K | 100 | METALL 100K | http://www.reichelt.de/1-4W-1-100-k-Ohm-976-k-Ohm/METALL-100K/3/index.html | 0,025 | 2,5 |  |  |  | 5 | Widerstände | 0,03 | 0,15 | 0,03 | 0,15
R2 | 22K | 100 | METALL 22,0K | http://www.reichelt.de/1-4W-1-10-0-k-Ohm-95-3-k-Ohm/METALL-22-0K/3/index.html | 0,025 | 2,5 |  |  |  | 2 | Taster | 0,10 | 0,20 | 0,07 | 0,14
R3 | 10K | 100 | METALL 10,0K | http://www.reichelt.de/1-4W-1-10-0-k-Ohm-95-3-k-Ohm/METALL-10-0K/3/index.html | 0,025 | 2,5 |  |  |  | 1 | Piezo Buzzer | 0,89 | 0,89 | 0,48 | 0,48
R4, R5 | 33R | 200 | METALL 33,0 | http://www.reichelt.de/1-4W-1-10-0-Ohm-97-6-Ohm/METALL-33-0/3/index.html | 0,025 | 5 |  |  |  | 3 | Kondensator | 0,04 | 0,12 | 0,04 | 0,12
Kurzschlussbrücke |  | 100 | JUMPER 2,54 RT | http://www.reichelt.de/Stiftleisten/JUMPER-2-54-RT/3/index.html | 0,05 | 5 |  |  |  | 2 | Stiftleiste 1x3 | 0,02 | 0,04 | 0,02 | 0,04
Stifleisten 36er |  | 50 | SL 1X36G 2,54 | http://www.reichelt.de/Stiftleisten/SL-1X36G-2-54/3/index.html | 0,16 | 8 |  |  |  | 1 | Stiftleiste 2x3 | 0,15 | 0,15 | 0,01 | 0,01
ESD-Matten |  | 2 | ESD PE-MOS 300 | http://www.reichelt.de/ESD-Verpackungsmaterial/ESD-PE-MOS-300/3/index.html | 1,45 | 2,9 |  |  |  | 2 | Buchsenleiste 1x5 (2x) | 0,26 | 0,52 | 0,26 | 0,52
 |  |  |  |  |  |  | Versand |  |  | 1 | Motor | 0,85 | 0,85 | 0,85 | 0,85
 |  |  |  |  |  | 141,25 | 146,85 |  |  | 2 | Transistor (2x) | 0,05 | 0,10 | 0,05 | 0,10
 |  |  |  |  |  |  |  |  |  | 1 | IR-Empfänger | 0,62 | 0,62 | 0,49 | 0,49
POLLIN |  |  |  |  |  |  |  |  |  | 2 | LED (2x) | 0,14 | 0,28 | 0,07 | 0,14
Motoren |  | 100 |  | http://www.pollin.de/shop/dt/MzY1OTg2OTk-/Motoren/Gleichstrommotoren/Vibrationsmotor.html | 0,85 | 85 |  |  |  | 2 | IR-LED (2x) | 0,40 | 0,80 | 0,17 | 0,34
 |  |  |  |  |  |  | Versand |  |  | 1 | Batteriefach | 0,82 | 0,82 | 0,58 | 0,58
 |  |  |  |  |  | 85 | 89,95 |  |  | 1 | Jumper | 0,05 | 0,05 | 0,05 | 0,05
 |  |  |  |  |  |  |  |  |  | 2 | Batterien | 0,20 | 0,40 | 0,20 | 0,40
 |  |  |  |  |  |  |  |  |  |  | Summe Bauteile |  | 8,39 |  | 5,78
VERPACKUNGSMATERIAL |  |  |  |  |  |  |  |  |  | 1 | Platine | ca. 40€ für 3 Stück |  | 2,14 | 2,14
Faltschachteln 105x50x75 |  | 1x100er |  | http://www.ebay.de/itm/Faltkartons-Faltschachteln-Geschenkkartons-100-Stuck-a-0-08-105x-50x-75-mm-/251270149020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 |  | 13,8 |  |  |  |  | Verpackung |  |  |  | 0,25
 |  |  |  |  |  |  |  |  |  |  | Porto Materialbestellungen (ca.) |  |  |  | 0,30
 |  |  |  |  |  |  |  |  |  |  | Verzierung, Verbrauchsmaterial (ca.) |  |  |  | 0,80
Zip-Tütchen 60x80 |  | 400stck |  | http://www.ebay.de/itm/W302C-40-400-Stk-ZIP-BEUTEL-Druckverschlussbeutel-60mm-x-80mm-Tutchen-60x80-mm-/130845880854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 |  | 6,5
 |  |  |  |  |  | 20,3 | 20,3 |  |  |  | SUMME |  |  |  | 9,27
DEKO-MATERIAL
Biegeplüsch |  |  |  | http://www.amazon.de/Chenilledraht-Pfeifenputzer-Kindergartenpackung-100-Stk/dp/B00472R884?s=kitchen |  | 10,49
Wackelaugen 7mm |  |  |  | http://www.amazon.de/Wackelaugen-rund-7mm-100-St%C3%BCck/dp/B00203YJ34?s=kitchen |  | 3,94
Wackelaugen bunt |  |  |  | http://www.amazon.de/Eduplay-Wackelaugen-Mix-Wimpern-teilig/dp/B001JPMDVE/ref=pd_sim_sbs_office_8 |  | 2,58
Glitzersteine |  |  |  | http://www.amazon.de/Hotfix-Farben-Strass-Strasssteine-Glitzersteine/dp/B00BZPQMII?s=toys |  | 8,99
Applikator für Glitzersteine |  |  |  | http://www.amazon.de/CFH-52920-Strassstein-Applikator-920/dp/B005VCZ156/ref=pd_sim_sbs_diy_1 |  | 15,49
 |  |  |  |  |  | 41,49 | 41,49
Niedrigtemperatur Schmelzkleber
2x Klebepistolen 110′C |  |  |  | http://www.creativ-discount.de/Maxi-Hei%C3%9Fklebepistole-Niedrigtemperatur-%D8-11mm.htm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 |  | 24,48 |  | (dort könnte man auch die dekomaterialien mitbestellen)
Klebesticks | 100 Stück |  |  | http://www.creativ-discount.de/Maxi-Klebesticks-%d8-11mm,-100-St%C3%BCck.htm?websale8=party-discount.creativ_web_de&pi=CCC39-132&ci=801-4561 |  | 20,79
 |  |  |  |  |  | 45,27 | 49,77

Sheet: EK2014_08
 | MOUSER
 | BAT1 | Batteriehalter 2xAAA | 200 | 12BH423-GR | http://de.mouser.com/ProductDetail/Eagle-Plastic-Devices/12BH423-GR/ | 0,49 | 98 | 0,59
x | IC1 | ATMEGA 88 | 200 | 556-ATMEGA88A-PU | http://de.mouser.com/ProductDetail/Atmel/ATMEGA88PA-PU/ | 1,04 | 208 | 1,24
 | IR1 | TSOP382 940nm 38KHz | 200 | TSOP38238 | http://www.mouser.de/ProductDetail/Vishay-Semiconductors/TSOP38238/ | 0,41 | 82 | 0,49
 | LED3, LED4 | LED3mm-IR | 400 | 638-IR204/H16/L10 | http://de.mouser.com/ProductDetail/Everlight/EL-IR204-H16-L10/ | 0,135 | 54 | 0,17
 | S1, S2 | TACSWITCH | 400 | 642-MJTP1230 (MJTP1230=PHAP33019 | http://de.mouser.com/ProductDetail/Apem/MJTP1230/?qs=sGAEpiMZZMsgGjVA3toVBBXi3RKSr1bKWt8e9G1JY2g%3d | 0,05 | 20 | 0,06
 | SG1 | BUZZER | 200 | 810-PS1720P02 | http://de.mouser.com/ProductDetail/TDK/PS1720P02/ | 0,393 | 78,6 | 0,47
 | LED grün |  | 0 | 604-WP7113LGD | http://de.mouser.com/ProductDetail/Kingbright/WP7113LGD/ | 0,046 | 0 | 0,06
 | LED gelb |  | 0 | 604-WP7113LYD | http://de.mouser.com/ProductDetail/Kingbright/WP7113LYD/ | 0,051 | 0 | 0,07
 | LED rot |  | 100 | 604-WP7113HD | http://www.mouser.de/ProductDetail/Kingbright/WP7113HD/?qs=sGAEpiMZZMvHYEB9WUp7EjKTTHySLdIIEWa7gYY0Y5M%3d | 0,054 | 5,4 | 0,07
 |  |  |  |  |  |  | 546
 | REICHELT
 | Batterien | AAA (40er Packs) | 5 | GPR AL 40XAAA | http://www.reichelt.de/Alkalinebatterien/GPR-AL-40XAAA/3/index.html | 7,95 | 39,75
 | C1, C2, C3 | 100nF | 0 | Z5U-2,5 100N | http://www.reichelt.de/Vielschicht-bedrahtet-Z5U-20-/Z5U-2-5-100N/3/index.html | 0,04 | 0
 | JP2 | PINHD 2x3 | 200 | MPE 087-2-006 | http://www.reichelt.de/Stiftleisten/MPE-087-2-006/3/index.html | 0,15 | 30
 | JP4, JP5 | PINHD 1x5 Fem | 400 | MPE 094-1-005 | http://www.reichelt.de/Buchsenleisten/MPE-094-1-005/3/index.html | 0,24 | 96
 | Q1, Q2 | 2N7000_TO92 | 400 | 2N 7000 | http://www.reichelt.de/2N-Transistoren/2N-7000/3//index.html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 | 0,05 | 20
 | R1 | 100K | 200 | METALL 100K | http://www.reichelt.de/1-4W-1-100-k-Ohm-976-k-Ohm/METALL-100K/3/index.html | 0,025 | 5
 | R2 | 22K | 200 | METALL 22,0K | http://www.reichelt.de/1-4W-1-10-0-k-Ohm-95-3-k-Ohm/METALL-22-0K/3/index.html | 0,025 | 5
 | R3 | 10K | 200 | METALL 10,0K | http://www.reichelt.de/1-4W-1-10-0-k-Ohm-95-3-k-Ohm/METALL-10-0K/3/index.html | 0,025 | 5
 | R4, R5 | 33R | 400 | METALL 33,0 | http://www.reichelt.de/1-4W-1-10-0-Ohm-97-6-Ohm/METALL-33-0/3/index.html | 0,025 | 10
 | Kurzschlussbrücke |  | 200 | JUMPER 2,54 RT | http://www.reichelt.de/Stiftleisten/JUMPER-2-54-RT/3/index.html | 0,05 | 10
 | Stifleisten 36er |  | 30 | SL 1X36G 2,54 | http://www.reichelt.de/Stiftleisten/SL-1X36G-2-54/3/index.html | 0,16 | 4,8
 | ESD-Matten |  | 4 | ESD PE-MOS 300 | http://www.reichelt.de/ESD-Verpackungsmaterial/ESD-PE-MOS-300/3/index.html | 1,45 | 5,8

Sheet: Sammelbestellung_08_2014
 |  |  |  |  |  | 1 |  |  | 2 |  |  | 3 |  |  | 4 |  |  | 5
 |  |  |  |  |  |  | FVDB |  |  | BL |  |  | DDB |  |  | ZLOPH |  |  | N“N
 |  | Stückkosten | Anz/bausatz |  |  | 30 |  |  | 20 |  |  | 20 |  |  | 20 |  |  | 10
Fertigungskosten, zoll, abfertigung | 429,1 | 1,07 | 1 | Platine | 1,07 |  | Platine | 30 |  | Platine | 20 |  | Platine | 20 |  | Platine | 20 |  | Platine | 10
 | 232,8 | 0,78 | 1 | Motor | 0,78 |  | Motor | 30 |  | Motor | 20 |  | Motor | 20 |  | Motor | 20 |  | Motor | 10
 |  | 0,59 | 1 | Batteriehalter 2xAAA | 0,59 |  | Batteriehalter 2xAAA | 30 |  | Batteriehalter 2xAAA | 20 |  | Batteriehalter 2xAAA | 20 |  | Batteriehalter 2xAAA | 20 |  | Batteriehalter 2xAAA | 10
 |  | 1,24 | 1 | ATMEGA 88 | 1,24 |  | ATMEGA 88 | 30 |  | ATMEGA 88 | 20 |  | ATMEGA 88 | 20 |  | ATMEGA 88 | 20 |  | ATMEGA 88 | 10
 |  | 0,49 | 1 | IR TSOP382 940nm | 0,49 |  | IR TSOP382 940nm | 30 |  | IR TSOP382 940nm | 20 |  | IR TSOP382 940nm | 20 |  | IR TSOP382 940nm | 20 |  | IR TSOP382 940nm | 10
 |  | 0,17 | 2 | LED3mm IR | 0,34 |  | LED3mm IR | 60 |  | LED3mm IR | 40 |  | LED3mm IR | 40 |  | LED3mm IR | 40 |  | LED3mm IR | 20
 |  | 0,06 | 2 | Tacswitch | 0,12 |  | Tacswitch | 60 |  | Tacswitch | 40 |  | Tacswitch | 40 |  | Tacswitch | 40 |  | Tacswitch | 20
 |  | 0,47 | 1 | Buzzer | 0,47 |  | Buzzer | 30 |  | Buzzer | 20 |  | Buzzer | 20 |  | Buzzer | 20 |  | Buzzer | 10
 |  | 0,07 | 2 | LED bunt 5mm | 0,14 |  | LED bunt 5mm | 60 |  | LED bunt 5mm | 40 |  | LED bunt 5mm | 40 |  | LED bunt 5mm | 40 |  | LED bunt 5mm | 20
 |  | 0,03 | 1 | 100K | 0,03 |  | 100K | 30 |  | 100K | 20 |  | 100K | 20 |  | 100K | 20 |  | 100K | 10
 |  | 0,03 | 1 | 22K | 0,03 |  | 22K | 30 |  | 22K | 20 |  | 22K | 20 |  | 22K | 20 |  | 22K | 10
 |  | 0,03 | 1 | 10K | 0,03 |  | 10K | 30 |  | 10K | 20 |  | 10K | 20 |  | 10K | 20 |  | 10K | 10
 |  | 0,03 | 2 | 33R | 0,06 |  | 33R | 60 |  | 33R | 40 |  | 33R | 40 |  | 33R | 40 |  | 33R | 20
 |  | 0,04 | 3 | 100nF | 0,12 |  | 100nF | 90 |  | 100nF | 60 |  | 100nF | 60 |  | 100nF | 60 |  | 100nF | 30
 |  | 0,15 | 1 | PINHD 2x3 | 0,15 |  | PINHD 2x3 | 30 |  | PINHD 2x3 | 20 |  | PINHD 2x3 | 20 |  | PINHD 2x3 | 20 |  | PINHD 2x3 | 10
 |  | 0,24 | 2 | PINHD 1x5 Fem | 0,48 |  | PINHD 1x5 Fem | 60 |  | PINHD 1x5 Fem | 40 |  | PINHD 1x5 Fem | 40 |  | PINHD 1x5 Fem | 40 |  | PINHD 1x5 Fem | 20
 |  | 0,05 | 2 | 2N7000_TO92 | 0,1 |  | 2N7000_TO92 | 60 |  | 2N7000_TO92 | 40 |  | 2N7000_TO92 | 40 |  | 2N7000_TO92 | 40 |  | 2N7000_TO92 | 20
 |  | 0,01 | 2 | PINHD 1x3 male | 0,02 |  | PINHD 1x3 male | 60 |  | PINHD 1x3 male | 40 |  | PINHD 1x3 male | 40 |  | PINHD 1x3 male | 40 |  | PINHD 1x3 male | 20
 |  | 0,05 | 1 | Jumper | 0,05 |  | Jumper | 30 |  | Jumper | 20 |  | Jumper | 20 |  | Jumper | 20 |  | Jumper | 10
 |  | 0,02 | 1 | ESD-Matte | 0,02
 |  | 0,03 | 1 | Versandanteil reichelt | 0,03
 |  | 0,2 |  | AAA (40er Packs) | 6,36

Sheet: EK2014_12
 |  | MOUSER
 | x | BAT1 | Batteriehalter 2xAAA | 100 | 12BH423-GR | http://de.mouser.com/ProductDetail/Eagle-Plastic-Devices/12BH423-GR/ | 0,49 | 49 |  | x
 | x | IC1 | ATMEGA 88 | 100 | 556-ATMEGA88A-PU | http://de.mouser.com/ProductDetail/Atmel/ATMEGA88PA-PU/ | 1,44 | 144 |  | x
 | x | IR1 | TSOP382 940nm 38KHz | 100 | TSOP38238 | http://www.mouser.de/ProductDetail/Vishay-Semiconductors/TSOP38238/ | 0,444 | 44,4 |  | x
 | x | LED3, LED4 | LED3mm-IR | 200 | 638-IR204/H16/L10 | http://de.mouser.com/ProductDetail/Everlight/EL-IR204-H16-L10/ | 0,146 | 29,2 |  | x
 | x | S1, S2 | TACSWITCH | 200 | 642-MJTP1230 (MJTP1230=PHAP33019 | http://de.mouser.com/ProductDetail/Apem/MJTP1230/?qs=sGAEpiMZZMsgGjVA3toVBBXi3RKSr1bKWt8e9G1JY2g%3d | 0,054 | 10,8 |  | x
 | x | SG1 | BUZZER | 100 | 810-PS1720P02 | http://de.mouser.com/ProductDetail/TDK/PS1720P02/ | 0,425 | 42,5 |  | x
 |  | LED grün |  | 200 | 604-WP7113LGD | http://de.mouser.com/ProductDetail/Kingbright/WP7113LGD/ | 0,061 | 12,2 |  | x
 |  | LED gelb |  | 200 | 604-WP7113LYD | http://de.mouser.com/ProductDetail/Kingbright/WP7113LYD/ | 0,061 | 12,2 |  | x
 |  | LED rot |  | 200 | 604-WP7113HD | http://www.mouser.de/ProductDetail/Kingbright/WP7113HD/?qs=sGAEpiMZZMvHYEB9WUp7EjKTTHySLdIIEWa7gYY0Y5M%3d | 0,059 | 11,8 |  | x
 |  | C1, C2, C3 | 100nF | 0 | 594-K104K15X7RF5TL2 | http://www.mouser.de/Search/ProductDetail.aspx | 0,038 | 0
 |  |  |  |  |  |  |  |  | 356,1
neko |  |  |  | 1 | 771-LPC1114FN28/1021 |  | 2,52 | 2,52
 |  |  |  | 1 | 700-MAX756CPA |  | 4,66 | 4,66
 |  |  |  | 2 | 859-LTP-3784E |  | 2,31 | 4,62
 |  |  |  | 1 | 771-PCF8583PN |  | 2,83 | 2,83 | 14,63 | 17,4097
alex |  |  | Molex ffc connector 40 pol | 2 | 538-501951-4000 |  | 1,77 | 3,54
 |  |  | SML LED gn 5mA | 50 | 859-LTSTC193KGKT5A (http://www.mouser.de/ProductDetail/Lite-On/LTST-C193KGKT-5A/?qs=sGAEpiMZZMseGfSY3csMkWzho3Jp4bsNqXDw1GKAdAU%3D) |  | 0,067 | 3,35
 |  |  | SMD Led Blau 5mA | 50 | 859-LTSTC193TBKT5A (http://www.mouser.de/ProductDetail/Lite-On/LTST-C193TBKT-5A/?qs=sGAEpiMZZMseGfSY3csMkTQVMbQ3YFst78owAYH3zIQ%3D) |  | 0,079 | 3,95
 |  |  | SMD Led rot 5mA | 50 | 859-LTSTC193KRKT5A (http://www.mouser.de/ProductDetail/Lite-On/LTST-C193KRKT-5A/) |  | 0,067 | 3,35
 |  |  | SMD Led gelb 5mA | 50 | 859-LTSTC193KSKT5A (http://www.mouser.de/ProductDetail/Lite-On/LTST-C193KSKT-5A/?qs=sGAEpiMZZMseGfSY3csMkTQVMbQ3YFstgRsrgutM1sQ%3D) |  | 0,067 | 3,35
 |  |  | Bipolartransistoren SMD | 100 | 863-MMBT3904LT1G |  | 0,03 | 3
 |  |  | FET SMD | 4 | 771-BUK9K18-40E115 |  | 0,96 | 3,84
 |  |  | 100nF SMD 0805 25V | 100 | 77-VJ0805V104MXBPBC |  | 0,019 | 1,9
 |  |  |  | 1 | 771-LPC1114FN28/1021 |  | 2,52 | 2,52
 |  |  |  | 2 | 859-LTP-3784E |  | 2,31 | 4,62 | 33,42 | 39,7698 | 404,15 | 480,9385
 |  | REICHELT
 |  | Batterien | AAA (40er Packs) | 5 | GPR AL 40XAAA | http://www.reichelt.de/Alkalinebatterien/GPR-AL-40XAAA/3/index.html | 7,95 | 39,75 |  | x
 | x | C1, C2, C3 | 100nF | 300 | Z5U-2,5 100N | http://www.reichelt.de/Vielschicht-bedrahtet-Z5U-20-/Z5U-2-5-100N/3/index.html | 0,04 | 12
 | x | JP2 | PINHD 2x3 | 100 | MPE 087-2-006 | http://www.reichelt.de/Stiftleisten/MPE-087-2-006/3/index.html | 0,15 | 15
 | x | JP4, JP5 | PINHD 1x5 Fem | 200 | MPE 094-1-005 | http://www.reichelt.de/Buchsenleisten/MPE-094-1-005/3/index.html | 0,24 | 48 |  | x
 | x | Q1, Q2 | 2N7000_TO92 | 200 | 2N 7000 | http://www.reichelt.de/2N-Transistoren/2N-7000/3//index.html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 | 0,09 | 18
 | x | R1 | 100K | 100 | METALL 100K | http://www.reichelt.de/1-4W-1-100-k-Ohm-976-k-Ohm/METALL-100K/3/index.html | 0,025 | 2,5
 | x | R2 | 22K | 100 | METALL 22,0K | http://www.reichelt.de/1-4W-1-10-0-k-Ohm-95-3-k-Ohm/METALL-22-0K/3/index.html | 0,025 | 2,5
 | x | R3 | 10K | 100 | METALL 10,0K | http://www.reichelt.de/1-4W-1-10-0-k-Ohm-95-3-k-Ohm/METALL-10-0K/3/index.html | 0,025 | 2,5
 | x | R4, R5 | 33R | 200 | METALL 33,0 | http://www.reichelt.de/1-4W-1-10-0-Ohm-97-6-Ohm/METALL-33-0/3/index.html | 0,025 | 5
 | x | Kurzschlussbrücke |  | 100 | JUMPER 2,54 RT | http://www.reichelt.de/Stiftleisten/JUMPER-2-54-RT/3/index.html | 0,05 | 5
 | x | Stifleisten 36er |  | 15 | SL 1X36G 2,54 | http://www.reichelt.de/Stiftleisten/SL-1X36G-2-54/3/index.html | 0,15 | 2,25
 |  | ESD-Matten |  | 2 | ESD PE-MOS 300 | http://www.reichelt.de/ESD-Verpackungsmaterial/ESD-PE-MOS-300/3/index.html | 1,45 | 2,9 |  | x
 |  |  |  |  |  |  |  |  | 155,4
alex
 |  | Bulei 13x2 |  | 5 | BL 2X13G8 2,54 |  | 0,28 | 1,4
 |  | Bulei 25x2 |  | 2 | BL 2X25G8 2,54 |  | 0,62 | 1,24
 |  | Buleiste 1x3 |  | 4 | MPE 094-1-003 |  | 0,16 | 0,64
 |  | Box header Pentagrammer |  | 3 | WSL 6G |  | 0,16 | 0,48
 |  | Pfostenbuchse Pentagrammer |  | 6 | PFL 6 |  | 0,24 | 1,44
 |  | attiny2313 |  | 3 | ATTINY 2313A-PU (http://www.reichelt.de/ATTINY-2313A-PU/3/index.html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) |  | 0,95 | 2,85
 |  | USB-Stecker pentagrammer |  | 3 | USB AWF |  | 0,23 | 0,69
 |  | resonator 12MHz |  | 3 | CST 12,00 |  | 0,18 | 0,54
 |  | Elko |  | 3 | SM 1,0/63RAD |  | 0,05 | 0,15
 |  | Zenerdioden pentagrammer |  | 6 | ZF 3,6 |  | 0,05 | 0,3
 |  | Vandalismus-Taster |  | 1 | VS GQ16F-RT |  | 7,55 | 7,55
 |  | Hohlstecker-Buchsen metall |  | 2 | HEBL 21 |  | 0,22 | 0,44
 |  | Hohlstecker-Buchsen-Print |  | 10 | HEBW 21 |  | 0,24 | 2,4 | 20,12 | 175,52

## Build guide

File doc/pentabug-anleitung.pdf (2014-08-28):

### Stückliste

IC1 | ATMEGA88PA | Einbaulage beachten!
R1 | Widerstand 100K braun-schwarz-schwarz-gelb-braun
R2 | Widerstand 22K | rot-rot-schwarz-rot-braun
R3 | Widerstand 10K | braun-schwarz-schwarz-rot-braun
R4, R5 | Widerstand 33Ω | orange-orange-schwarz-gold-braun
S1, S2 | Taster
SG1 | Piezo Buzzer
C1, C2, C3 | Kondensator 100nF
JP1, JP3 | Stiftleiste 1x3
JP2 | Stiftleiste 2x3
JP4, JP5 | Buchsenleiste 1x5
M1 | Motor | an die quadratische Lötpads
Q1, Q2 | Transistor 2N7000 Einbaulage beachten!
IR | IR-Empfänger | Einbaulage beachten!
LED1, LED2 LED farbig | Polarität beachten!
LED3, LED4 IR-LED klar | Polarität beachten!
BAT1 | Batteriefach | vor Einbau Schaltung testen
| Jumper | auf Dreier-Stiftleiste stecken

### Stückliste

IC1 | ATMEGA88PA | Einbaulage beachten!
R1 | Widerstand 100K braun-schwarz-schwarz-gelb-braun
R2 | Widerstand 22K | rot-rot-schwarz-rot-braun
R3 | Widerstand 10K | braun-schwarz-schwarz-rot-braun
R4, R5 | Widerstand 33Ω | orange-orange-schwarz-gold-braun
S1, S2 | Taster
SG1 | Piezo Buzzer
C1, C2, C3 | Kondensator 100nF
JP1, JP3 | Stiftleiste 1x3
JP2 | Stiftleiste 2x3
JP4, JP5 | Buchsenleiste 1x5
M1 | Motor | an die quadratische Lötpads
Q1, Q2 | Transistor 2N7000 Einbaulage beachten!
IR | IR-Empfänger | Einbaulage beachten!
LED1, LED2 LED farbig | Polarität beachten!
LED3, LED4 IR-LED klar | Polarität beachten!
BAT1 | Batteriefach | vor Einbau Schaltung testen
| Jumper | auf Dreier-Stiftleiste stecken

### Stückliste

IC1 | ATMEGA88PA | Einbaulage beachten!
R1 | Widerstand 100K braun-schwarz-schwarz-gelb-braun
R2 | Widerstand 22K | rot-rot-schwarz-rot-braun
R3 | Widerstand 10K | braun-schwarz-schwarz-rot-braun
R4, R5 | Widerstand 33Ω | orange-orange-schwarz-gold-braun
S1, S2 | Taster
SG1 | Piezo Buzzer
C1, C2, C3 | Kondensator 100nF
JP1, JP3 | Stiftleiste 1x3
JP2 | Stiftleiste 2x3
JP4, JP5 | Buchsenleiste 1x5
M1 | Motor | an die quadratische Lötpads
Q1, Q2 | Transistor 2N7000 Einbaulage beachten!
IR | IR-Empfänger | Einbaulage beachten!
LED1, LED2 LED farbig | Polarität beachten!
LED3, LED4 IR-LED klar | Polarität beachten!
BAT1 | Batteriefach | vor Einbau Schaltung testen
| Jumper | auf Dreier-Stiftleiste stecken

### Stückliste

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

### Aufbau

Die Bauteile in der Reihenfolge der Stückliste
in die Platine stecken
und verlöten. Bei IC1, Q1,
Q2, IR, den LEDs und dem
Batteriefach die Einbaurichtung
beachten.
Die flachen Seiten der LEDs (kurzes Bein) zeigen stets in die gleiche Richtung, zum oberen Platinenrand. Hier kannst Du die Beine länger lassen und die LEDs nach vorn umbiegen. Bevor Du das Batteriefach montierst, teste die Funktion, da das Fach einige Lötstellen verdeckt! Zuletzt den Jumper in Stellung BAT auf die Dreier-Stiftleiste stecken. Wenn der Käfer mit dem voreingestellten Testprogramm blinkt, piepst und wackelt, dann stimmt vermutlich alles. Nun kannst Du den Käfer noch verzieren (Fühler gefällig?) und Deine eigenen Programme auf den Controller laden.

### Aufbau

Die Bauteile in der Reihenfolge der Stückliste
in die Platine stecken
und verlöten. Bei IC1, Q1,
Q2, IR, den LEDs und dem
Batteriefach die Einbaurichtung
beachten.
Die flachen Seiten der LEDs (kurzes Bein) zeigen stets in die gleiche Richtung, zum oberen Platinenrand. Hier kannst Du die Beine länger lassen und die LEDs nach vorn umbiegen. Bevor Du das Batteriefach montierst, teste die Funktion, da das Fach einige Lötstellen verdeckt! Zuletzt den Jumper in Stellung BAT auf die Dreier-Stiftleiste stecken. Wenn der Käfer mit dem voreingestellten Testprogramm blinkt, piepst und wackelt, dann stimmt vermutlich alles. Nun kannst Du den Käfer noch verzieren (Fühler gefällig?) und Deine eigenen Programme auf den Controller laden.

### Aufbau

Die Bauteile in der Reihenfolge der Stückliste
in die Platine stecken
und verlöten. Bei IC1, Q1,
Q2, IR, den LEDs und dem
Batteriefach die Einbaurichtung
beachten.
Die flachen Seiten der LEDs (kurzes Bein) zeigen stets in die gleiche Richtung, zum oberen Platinenrand. Hier kannst Du die Beine länger lassen und die LEDs nach vorn umbiegen. Bevor Du das Batteriefach montierst, teste die Funktion, da das Fach einige Lötstellen verdeckt! Zuletzt den Jumper in Stellung BAT auf die Dreier-Stiftleiste stecken. Wenn der Käfer mit dem voreingestellten Testprogramm blinkt, piepst und wackelt, dann stimmt vermutlich alles. Nun kannst Du den Käfer noch verzieren (Fühler gefällig?) und Deine eigenen Programme auf den Controller laden.

### Aufbau

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

### Links

Projektdateien, Schaltplan, Software: https://github.com/c3d2/pentabug | weitere Infos: https://www.c3d2.de/wiki/Pentabug
Löten ist einfach: http://mightyohm.com/files/soldercomic/translations/DE_SolderComic.pdf
Lizenz CC-BY-SA http://creativecommons.org/licenses/by-sa/3.0/ Chaos Computer Club Dresden 2013

### Links

Projektdateien, Schaltplan, Software: https://github.com/c3d2/pentabug | weitere Infos: https://www.c3d2.de/wiki/Pentabug
Löten ist einfach: http://mightyohm.com/files/soldercomic/translations/DE_SolderComic.pdf
Lizenz CC-BY-SA http://creativecommons.org/licenses/by-sa/3.0/ Chaos Computer Club Dresden 2013

### Links

Projektdateien, Schaltplan, Software: https://github.com/c3d2/pentabug | weitere Infos: https://www.c3d2.de/wiki/Pentabug
Löten ist einfach: http://mightyohm.com/files/soldercomic/translations/DE_SolderComic.pdf
Lizenz CC-BY-SA http://creativecommons.org/licenses/by-sa/3.0/ Chaos Computer Club Dresden 2013

### Links

Projektdateien, Schaltplan, Software: https://github.com/c3d2/pentabug | weitere Infos: https://www.c3d2.de/wiki/Pentabug
Löten ist einfach: http://mightyohm.com/files/soldercomic/translations/DE_SolderComic.pdf
Lizenz CC-BY-SA http://creativecommons.org/licenses/by-sa/3.0/ Chaos Computer Club Dresden 2013
Pentabug | Pentabug
Pentabug | Pentabug

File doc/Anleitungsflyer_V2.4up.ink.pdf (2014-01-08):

# pentabug Bausatz

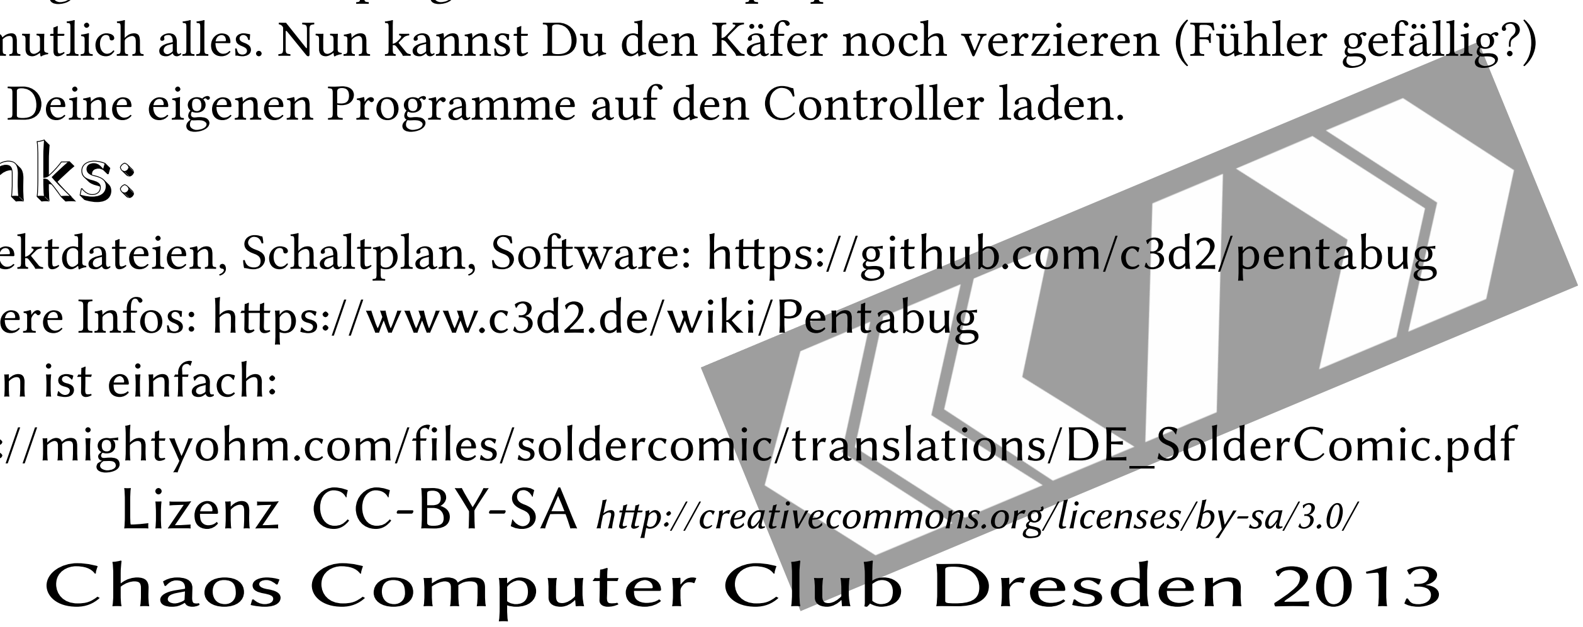
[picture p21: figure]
Chaos Computer Club Dresden 2013

## Links:

Projektdateien, Schaltplan, Soware: hps://github.com/c3d2/pentabug weitere Infos: hps://www.c3d2.de/wiki/Pentabug
Löten ist einfach:
hp://mightyohm.com/files/soldercomic/translations/DE_SolderComic.pdf

## Stückliste:

IC1 | ATMEGA88PA | Einbaulage beachten!
R1 | Widerstand 100K braun-schwarz-schwarz-gelb-braun
R2 | Widerstand 22K | rot-rot-schwarz-rot-braun
R3 | Widerstand 10K | braun-schwarz-schwarz-rot-braun
R4, R5 | Widerstand 33Ω | orange-orange-schwarz-gold-braun
S1, S2 | Taster
SG1 | Piezo Buzzer
C1, C2, C3 | Kondensator 100nF
JP1, JP3 | Stileiste 1x3 | kurze Seite einlöten
JP2 | Stileiste 2x3 | kurze Seite einlöten
JP4, JP5 | Buchsenleiste 1x5
M1 | Motor | an die quadratische Lötpads
Q1, Q2 | Transistor 2N7000 Einbaulage beachten!
IR | IR-Empänger | Einbaulage beachten!
LED1, LED2 LED farbig | Polarität beachten!
LED3, LED4 IR-LED klar | Polarität beachten!
BAT1 | Baeriefach | vor Einbau Schaltung testen

## Aufbau:

Die Bauteile in der Reihenfolge der Stückliste in die Platine stecken und verlöten. Bei IC1, Q1, Q2, IR, den LEDs und dem Baeriefach die Einbaurichtung beachten. Die flachen Seiten der LEDs (kurzes Bein) zeigen stets in die gleiche Richtung, zum oberen Platinenrand. Hier kannst Du die Beine länger lassen und die LEDs nach vorn umbiegen. Bevor Du das Baeriefach montierst, teste die Funktion, da das Fach einige Lötstellen verdeckt! Wenn Der Käfer mit dem voreingestellten Testprogramm blinkt, piepst und wackelt, dann stimmt vermutlich alles. Nun kannst Du den Käfer noch verzieren (Fühler geällig?) und Deine eigenen Programme auf den Controller laden.

Lizenz CC-BY-SA hp://creativecommons.org/licenses/by-sa/3.0/

# V2.0 pentabug Bausatz

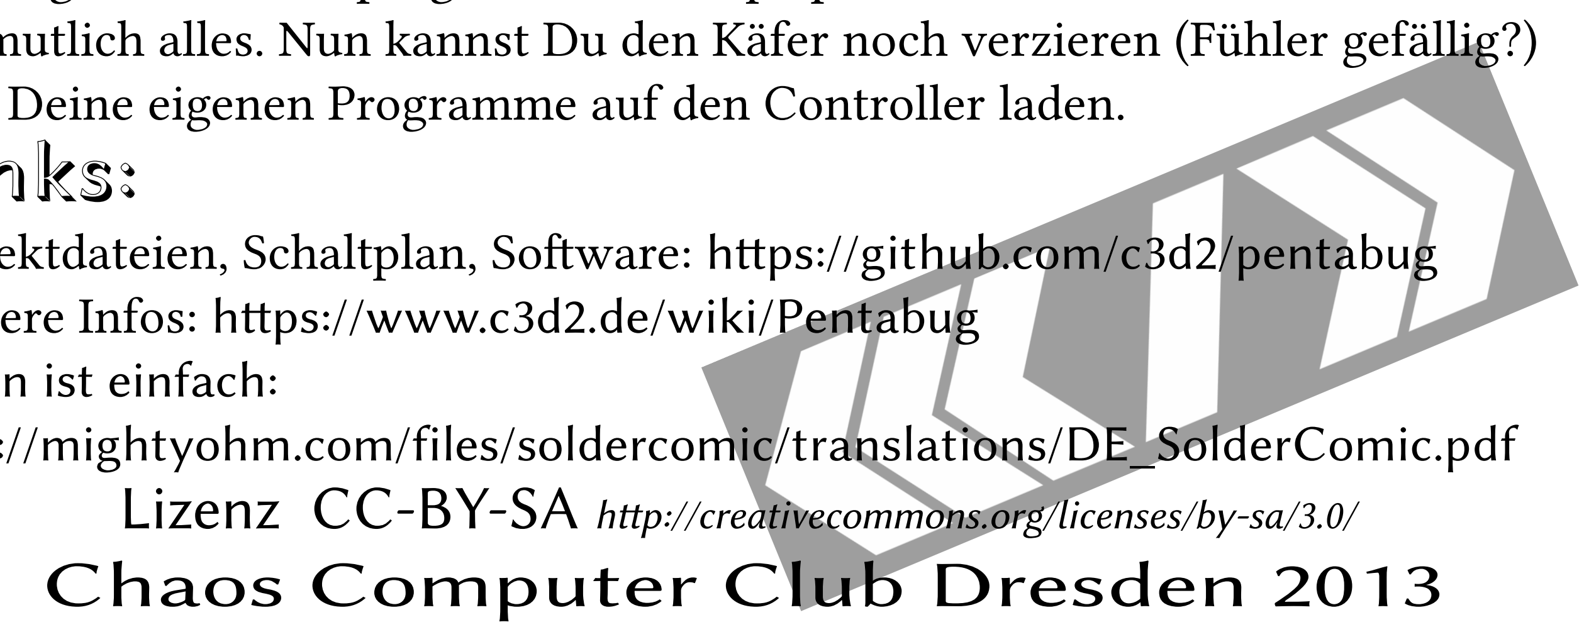
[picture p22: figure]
Chaos Computer Club Dresden 2013

## Links:

Projektdateien, Schaltplan, Soware: hps://github.com/c3d2/pentabug weitere Infos: hps://www.c3d2.de/wiki/Pentabug
Löten ist einfach:
hp://mightyohm.com/files/soldercomic/translations/DE_SolderComic.pdf

## Stückliste:

IC1 | ATMEGA88PA | Einbaulage beachten!
R1 | Widerstand 100K braun-schwarz-schwarz-gelb-braun
R2 | Widerstand 22K | rot-rot-schwarz-rot-braun
R3 | Widerstand 10K | braun-schwarz-schwarz-rot-braun
R4, R5 | Widerstand 33Ω | orange-orange-schwarz-gold-braun
S1, S2 | Taster
SG1 | Piezo Buzzer
C1, C2, C3 | Kondensator 100nF
JP1, JP3 | Stileiste 1x3 | kurze Seite einlöten
JP2 | Stileiste 2x3 | kurze Seite einlöten
JP4, JP5 | Buchsenleiste 1x5
M1 | Motor | an die quadratische Lötpads
Q1, Q2 | Transistor 2N7000 Einbaulage beachten!
IR | IR-Empänger | Einbaulage beachten!
LED1, LED2 LED farbig | Polarität beachten!
LED3, LED4 IR-LED klar | Polarität beachten!
BAT1 | Baeriefach | vor Einbau Schaltung testen

## Aufbau:

Die Bauteile in der Reihenfolge der Stückliste in die Platine stecken und verlöten. Bei IC1, Q1, Q2, IR, den LEDs und dem Baeriefach die Einbaurichtung beachten. Die flachen Seiten der LEDs (kurzes Bein) zeigen stets in die gleiche Richtung, zum oberen Platinenrand. Hier kannst Du die Beine länger lassen und die LEDs nach vorn umbiegen. Bevor Du das Baeriefach montierst, teste die Funktion, da das Fach einige Lötstellen verdeckt! Wenn Der Käfer mit dem voreingestellten Testprogramm blinkt, piepst und wackelt, dann stimmt vermutlich alles. Nun kannst Du den Käfer noch verzieren (Fühler geällig?) und Deine eigenen Programme auf den Controller laden.

Lizenz CC-BY-SA hp://creativecommons.org/licenses/by-sa/3.0/

V2.0

# pentabug Bausatz

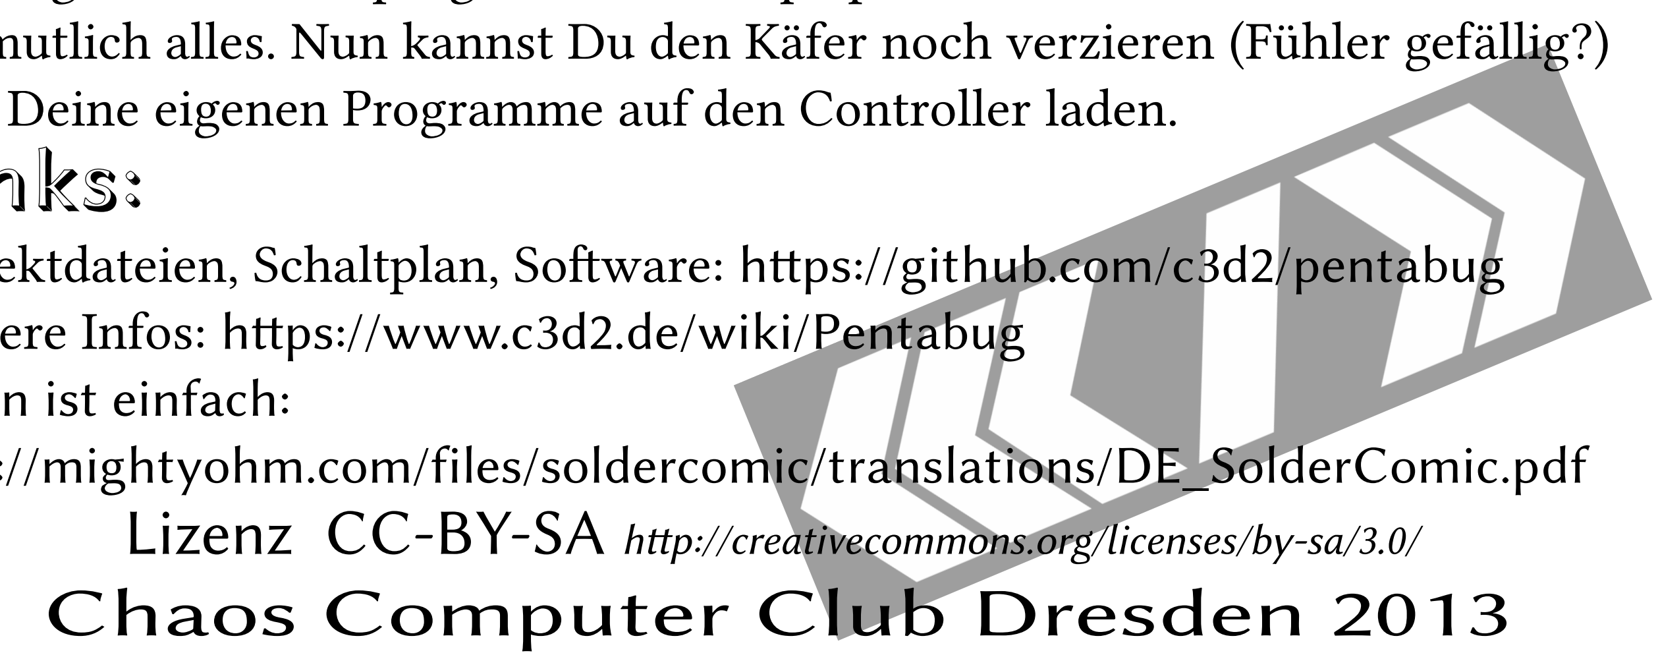
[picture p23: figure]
Chaos Computer Club Dresden 2013

## Links:

Projektdateien, Schaltplan, Soware: hps://github.com/c3d2/pentabug weitere Infos: hps://www.c3d2.de/wiki/Pentabug
Löten ist einfach:
hp://mightyohm.com/files/soldercomic/translations/DE_SolderComic.pdf

## Stückliste:

IC1 | ATMEGA88PA | Einbaulage beachten!
R1 | Widerstand 100K braun-schwarz-schwarz-gelb-braun
R2 | Widerstand 22K | rot-rot-schwarz-rot-braun
R3 | Widerstand 10K | braun-schwarz-schwarz-rot-braun
R4, R5 | Widerstand 33Ω | orange-orange-schwarz-gold-braun
S1, S2 | Taster
SG1 | Piezo Buzzer
C1, C2, C3 | Kondensator 100nF
JP1, JP3 | Stileiste 1x3 | kurze Seite einlöten
JP2 | Stileiste 2x3 | kurze Seite einlöten
JP4, JP5 | Buchsenleiste 1x5
M1 | Motor | an die quadratische Lötpads
Q1, Q2 | Transistor 2N7000 Einbaulage beachten!
IR | IR-Empänger | Einbaulage beachten!
LED1, LED2 LED farbig | Polarität beachten!
LED3, LED4 IR-LED klar | Polarität beachten!
BAT1 | Baeriefach | vor Einbau Schaltung testen

## Aufbau:

Die Bauteile in der Reihenfolge der Stückliste in die Platine stecken und verlöten. Bei IC1, Q1, Q2, IR, den LEDs und dem Baeriefach die Einbaurichtung beachten. Die flachen Seiten der LEDs (kurzes Bein) zeigen stets in die gleiche Richtung, zum oberen Platinenrand. Hier kannst Du die Beine länger lassen und die LEDs nach vorn umbiegen. Bevor Du das Baeriefach montierst, teste die Funktion, da das Fach einige Lötstellen verdeckt! Wenn Der Käfer mit dem voreingestellten Testprogramm blinkt, piepst und wackelt, dann stimmt vermutlich alles. Nun kannst Du den Käfer noch verzieren (Fühler geällig?) und Deine eigenen Programme auf den Controller laden.

Lizenz CC-BY-SA hp://creativecommons.org/licenses/by-sa/3.0/

# V2.0 pentabug Bausatz

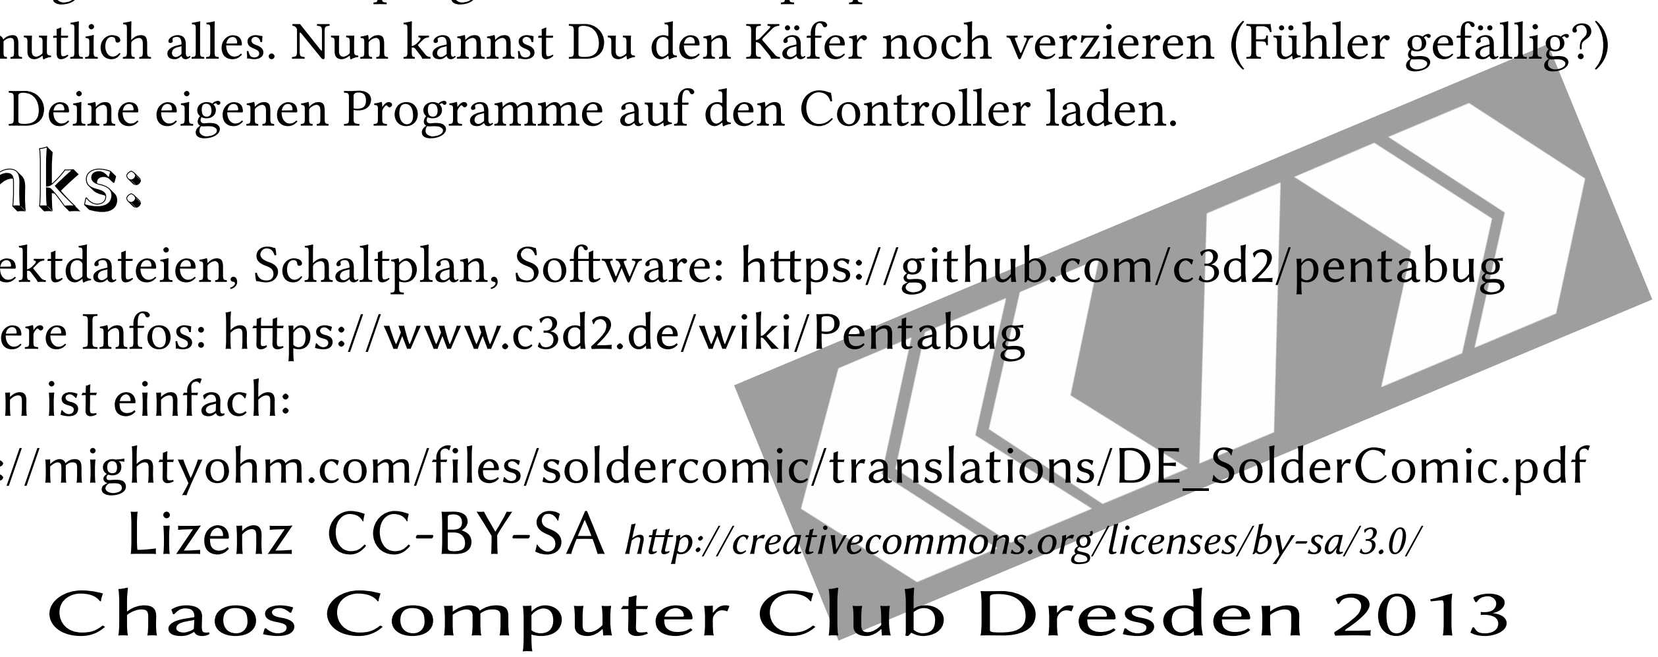
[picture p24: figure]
Chaos Computer Club Dresden 2013

## Links:

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

## Stückliste:

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

## Aufbau:

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

Lizenz CC-BY-SA hp://creativecommons.org/licenses/by-sa/3.0/

V2.0

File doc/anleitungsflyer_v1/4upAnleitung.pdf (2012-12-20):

# pentabug Bausatz

## Links:

Projektdateien, Schaltplan, Soware: hps://github.com/c3d2/pentabug weitere Infos:
hps://www.c3d2.de/wiki/Pentabug
Löten ist einfach:
hp://mightyohm.com/files/soldercomic/translations/DE_SolderComic.pdf

## Stückliste:

IC1 | ATMEGA88PA | Einbaulage beachten
R1 | Widerstand 100K braun-schwarz-schwarz-gelb-braun
R2 | Widerstand 22K | rot-rot-schwarz-rot-braun
R3 | Widerstand 10K | braun-schwarz-schwarz-rot-braun
Q1 | Transistor 2N7000 Einbaulage beachten
C1, C2, C3 | Kondensator 100nF
LED1, LED2 LED Rot | Polarität beachten
SG1 | Piezo Buzzer
JP1 | Stileiste 1x3
JP2 | Stileiste 2x3
S1, S2 | Taster
M1 | Motor
BAT1 | Baeriefach | vor Einbau Schaltung testen

## Aufbau:

Die Bauteile in der Reihenfolge der Stückliste in die Platine stecken und verlöten. Bei IC1, Q1, den LEDs und dem Baeriefach die Einbaurichtung beachten. Bevor Du das Baeriefach montierst, solltest Du die Funktion überprüfen, da das Fach einige Lötstellen verdeckt! Wenn der Käfer mit dem voreingestellten Testprogramm blinkt, piepst und wackelt, dann stimmt vermutlich alles. Nun kannst Du den Käfer noch verzieren (Fühler geällig?) und Deine eigenen Programme auf den Controller laden.
ACHTUNG: Vor Anschließen des Programmers immer Baerien entnehmen!

Lizenz CC-BY-SA hp://creativecommons.org/licenses/by-sa/3.0/

## Chaos Computer Club Dresden 2012

# V1.0 pentabug Bausatz

## Links:

Projektdateien, Schaltplan, Soware: hps://github.com/c3d2/pentabug weitere Infos:
hps://www.c3d2.de/wiki/Pentabug
Löten ist einfach:
hp://mightyohm.com/files/soldercomic/translations/DE_SolderComic.pdf

## Stückliste:

IC1 | ATMEGA88PA | Einbaulage beachten
R1 | Widerstand 100K braun-schwarz-schwarz-gelb-braun
R2 | Widerstand 22K | rot-rot-schwarz-rot-braun
R3 | Widerstand 10K | braun-schwarz-schwarz-rot-braun
Q1 | Transistor 2N7000 Einbaulage beachten
C1, C2, C3 | Kondensator 100nF
LED1, LED2 LED Rot | Polarität beachten
SG1 | Piezo Buzzer
JP1 | Stileiste 1x3
JP2 | Stileiste 2x3
S1, S2 | Taster
M1 | Motor
BAT1 | Baeriefach | vor Einbau Schaltung testen

## Aufbau:

Die Bauteile in der Reihenfolge der Stückliste in die Platine stecken und verlöten. Bei IC1, Q1, den LEDs und dem Baeriefach die Einbaurichtung beachten. Bevor Du das Baeriefach montierst, solltest Du die Funktion überprüfen, da das Fach einige Lötstellen verdeckt! Wenn der Käfer mit dem voreingestellten Testprogramm blinkt, piepst und wackelt, dann stimmt vermutlich alles. Nun kannst Du den Käfer noch verzieren (Fühler geällig?) und Deine eigenen Programme auf den Controller laden.
ACHTUNG: Vor Anschließen des Programmers immer Baerien entnehmen!

Lizenz CC-BY-SA hp://creativecommons.org/licenses/by-sa/3.0/

## Chaos Computer Club Dresden 2012

V1.0

# pentabug Bausatz

## Links:

Projektdateien, Schaltplan, Soware: hps://github.com/c3d2/pentabug weitere Infos:
hps://www.c3d2.de/wiki/Pentabug
Löten ist einfach:
hp://mightyohm.com/files/soldercomic/translations/DE_SolderComic.pdf

## Stückliste:

IC1 | ATMEGA88PA | Einbaulage beachten
R1 | Widerstand 100K braun-schwarz-schwarz-gelb-braun
R2 | Widerstand 22K | rot-rot-schwarz-rot-braun
R3 | Widerstand 10K | braun-schwarz-schwarz-rot-braun
Q1 | Transistor 2N7000 Einbaulage beachten
C1, C2, C3 | Kondensator 100nF
LED1, LED2 LED Rot | Polarität beachten
SG1 | Piezo Buzzer
JP1 | Stileiste 1x3
JP2 | Stileiste 2x3
S1, S2 | Taster
M1 | Motor
BAT1 | Baeriefach | vor Einbau Schaltung testen

## Aufbau:

Die Bauteile in der Reihenfolge der Stückliste in die Platine stecken und verlöten. Bei IC1, Q1, den LEDs und dem Baeriefach die Einbaurichtung beachten. Bevor Du das Baeriefach montierst, solltest Du die Funktion überprüfen, da das Fach einige Lötstellen verdeckt! Wenn der Käfer mit dem voreingestellten Testprogramm blinkt, piepst und wackelt, dann stimmt vermutlich alles. Nun kannst Du den Käfer noch verzieren (Fühler geällig?) und Deine eigenen Programme auf den Controller laden.
ACHTUNG: Vor Anschließen des Programmers immer Baerien entnehmen!

Lizenz CC-BY-SA hp://creativecommons.org/licenses/by-sa/3.0/

## Chaos Computer Club Dresden 2012

# V1.0 pentabug Bausatz

## Links:

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

## Stückliste:

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

## Aufbau:

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

Lizenz CC-BY-SA hp://creativecommons.org/licenses/by-sa/3.0/

## Chaos Computer Club Dresden 2012

V1.0

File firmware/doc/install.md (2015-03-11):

# Installation

Diese Anleitung geht davon aus, dass du ein Ubuntu, Debian oder ein ähnliches
Linux vor dir hast. Es wird grundlegendes Wissen im Umgang mit der Kommandozeile
vorausgesetzt.

Als erstes müssen die benötigten Programme installiert werden:

	sudo apt-get install avr-libc avrdude gcc-avr build-essential

Danach kannst du dir den Quellcode für die Firmware des Bugs herunterladen.
Bewege dich dafür in das Verzeichnis in das du den Quellcode kopieren möchtest
und führe folgenden Befehl aus:

	git clone https://github.com/c3d2/pentabug.git

Jetzt hast du einen neuen Ordner namens `pentabug` in dem sich die Firmware
befindet:

	cd pentabug/firmware/

Nun kannst du den menschenlesbaren Quellcode in maschinenlesbare Befehle
überführen. Diesen Vorgang nennt man Kompillieren. Dabei unterstützt dich das
sogenannte `Makefile`, dass automatisch überprüft welche Dateien nicht vorhanden
sind oder geändert wurden 

	make

Wenn der Befehl oben erfolgreich durchgelaufen ist kannst du die Firmware mit
folgendem Befehl auf deinen Pentabug laden:

	make flsmart

Nun kannst du anfangen den Quellcode anpassen und deine eigenen Programme
entwerfen. Die einzelnen Programme befinden sich im Ordner

	pentabug/firmware/app/

Jedes mal wenn du eine Änderung ausprobieren willst musst die wieder das
Makefile ausführen mit folgenden Befehlen

	make
	make flsmart

Wenn du ein neues Programm anlegst oder ein existierendes Programm aus der
Firmware für deinen Pentabug entfernen musst du die erste Zeile folgender Datei
editieren:

	pentabug/firmware/Makefile

Die einzelnen Einträge hier entsprechen den Dateinamen in

	pentabug/firmware/app/

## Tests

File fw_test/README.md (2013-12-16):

# Test firmware

Use this firmware to test all hardware components of a Pentabug. It can test
nearly all hardware features of the device. It offers the following features:

* the left led blinks when no input is present
* receiving an IR signal activates the right led
* pressing the left button sends an IR signal (triggering the right led)
* pressing the right button activates the motor
* each button plays a sound using a different pin of the buzzer
* the pins of the extension board are constantly cycled through (add a
  pentatonic to visualize all but one pin)

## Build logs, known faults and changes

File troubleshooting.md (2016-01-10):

# Troubleshooting

### That peculiar bug reacts sluggishly or slowly and doesn't "feel" right

Check that the fuses are correctly set to work at 8 MHz. Fuses should be `-U lfuse:w:0xe2:m -U hfuse:w:0xdf:m -U efuse:w:0x01:m` 

### I checked the connections to the ISP pins but flashing firmware still fails

See [issue #23](https://github.com/c3d2/pentabug/issues/23) and try to omit the `-B 1` switch in the makefile.

### My bug does not respond to light

See [issue #21](https://github.com/c3d2/pentabug/issues/21) and help us fixing this in the firmware.

### My bug does not respond to sound very well

See [issue #22](https://github.com/c3d2/pentabug/issues/22) and help us fixing this in the firmware.

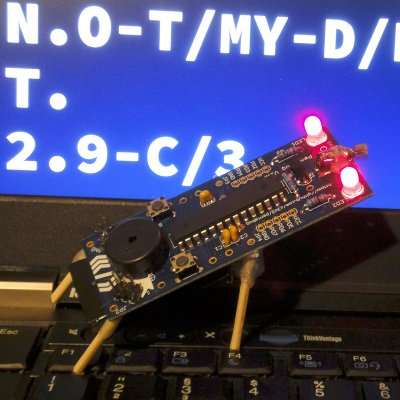
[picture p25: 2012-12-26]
img/29c3bug_400.jpg

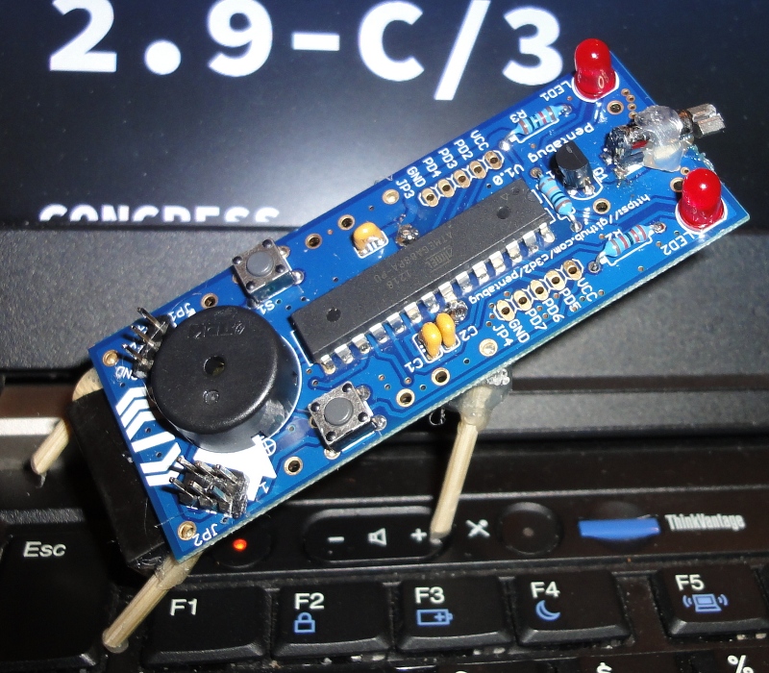
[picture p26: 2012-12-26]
img/29c3bug_800x700.jpg

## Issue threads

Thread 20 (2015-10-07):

LED Matrix

plushvoxel, 2015-10-07:
Hey, I tried to build the LED matrix from the pentabug_v2.brd file.
It doesn't seem to operate correctly. Also some LEDs are dimmed.

Is this a reproduceable problem or am I the only one experiencing this?

Closed 2015-10-07.

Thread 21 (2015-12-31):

Manche Bugs resagieren nicht richtig auf Licht

alxlo, 2015-12-31:
Liegt and den unterschiedlichen LEDs. sollte in Software zu fixen sein (Messroutine für die Helligkeit).

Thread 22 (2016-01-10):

Some of the bugs from the 12/2015 batch do not respond that good to sound.

alxlo, 2016-01-10:
For some of the bugs we had to use different buzzers due to availability reasons. Usually we use[TDK PS1720P02](www.mouser.de/ProductDetail/TDK/PS1720P02) but on about 50 bugs there will be the [TDK 810-PS1740P02E](http://www.mouser.de/ProductDetail/TDK/PS1740P02E/) that seem to respond to sound and vibration not as good as the original ones. This should be solvable in software by lowering tresholds.

The 810-PS1740P02E has a resonance frequency of 4KHz (instead of 2KHz) and is 0.5 mm lower than the original.

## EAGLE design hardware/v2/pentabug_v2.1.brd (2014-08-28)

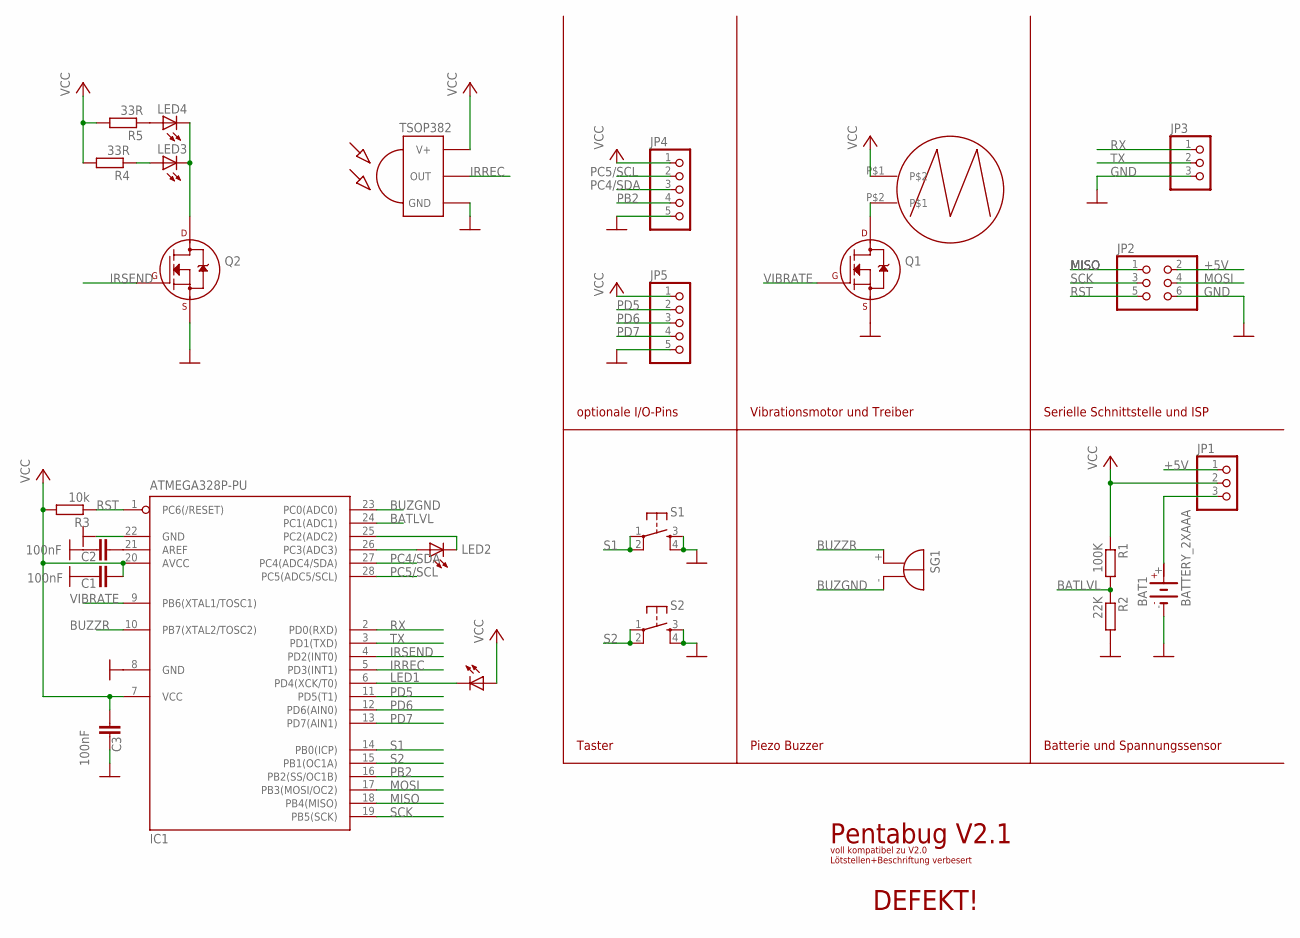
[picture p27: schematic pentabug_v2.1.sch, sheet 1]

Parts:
BAT1: BATTERY_2XAAA; BATTERY_2XAAA_SMALLPINS
C1, C2, C3: 100nF; C025-024X044
IC1: ATMEGA328P-PU; DIL28-3
IR: TSOP382
JP1, JP3: PINHD-1X3; 1X03
JP2: PINHD-2X3; 2X03
JP4, JP5: PINHD-1X5; 1X05
LED1, LED2: LED5MM
LED3, LED4: LED3MM
Q1, Q2: 2N7000; TO92-
R1: 100K; 0207/10
R2: 22K; 0207/10
R3: 10k; 0207/10
R4, R5: 33R; 0207/10
S1, S2: TAC_SWITCHPTH; TACTILE-PTH
SG1: MULTIBUZZRTDKBUZZR; BUZZRTDK
U$1: VIBRAMOTOR; LA4-432

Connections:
+5V: JP1.1, JP2.2
BAT: BAT1.+, JP1.3
BATLVL: IC1.24 (PC1(ADC1)), R1.2, R2.1
BUZGND: IC1.23 (PC0(ADC0)), SG1.-
BUZZR: IC1.10 (PB7(XTAL2/TOSC2)), SG1.+
GND: BAT1.-, C1.1, C2.1, C3.1, IC1.8 (GND), IC1.22 (GND), IR.GND, JP2.6, JP3.3, JP4.5, JP5.5, Q1.1 (S), Q2.1 (S), R2.2, S1.3, S1.4, S2.3, S2.4
IRREC: IC1.5 (PD3(INT1)), IR.OUT
IRSEND: IC1.4 (PD2(INT0)), Q2.2 (G)
MISO: IC1.18 (PB4(MISO)), JP2.1
MOSI: IC1.17 (PB3(MOSI/OC2)), JP2.4
unnamed: IC1.26 (PC3(ADC3)), LED2.A
unnamed: IC1.25 (PC2(ADC2)), LED2.K (C)
unnamed: LED4.A, R5.1
unnamed: Q1.3 (D), U$1.P$2
unnamed: LED3.A, R4.1
unnamed: LED3.K (C), LED4.K (C), Q2.3 (D)
unnamed: IC1.6 (PD4(XCK/T0)), LED1.K (C)
unnamed: C2.2, IC1.21 (AREF)
PB2: IC1.16 (PB2(SS/OC1B)), JP4.4
PC4/SDA: IC1.27 (PC4(ADC4/SDA)), JP4.3
PC5/SCL: IC1.28 (PC5(ADC5/SCL)), JP4.2
PD5: IC1.11 (PD5(T1)), JP5.2
PD6: IC1.12 (PD6(AIN0)), JP5.3
PD7: IC1.13 (PD7(AIN1)), JP5.4
RST: IC1.1 (PC6(/RESET)), JP2.5, R3.1
RX: IC1.2 (PD0(RXD)), JP3.1
S1: IC1.14 (PB0(ICP)), S1.1, S1.2
S2: IC1.15 (PB1(OC1A)), S2.1, S2.2
SCK: IC1.19 (PB5(SCK)), JP2.3
TX: IC1.3 (PD1(TXD)), JP3.2
VCC: C1.2, C3.2, IC1.7 (VCC), IC1.20 (AVCC), IR.VCC (V+), JP1.2, JP4.1, JP5.1, LED1.A, R1.1, R3.2, R4.2, R5.2, U$1.P$1
VIBRATE: IC1.9 (PB6(XTAL1/TOSC1)), Q1.2 (G)

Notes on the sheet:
Serielle Schnittstelle und ISP
DEFEKT!
Vibrationsmotor und Treiber
optionale I/O-Pins
Taster
Piezo Buzzer
Batterie und Spannungssensor
Pentabug V2.1
voll kompatibel zu V2.0 Lötstellen+Beschriftung verbesert

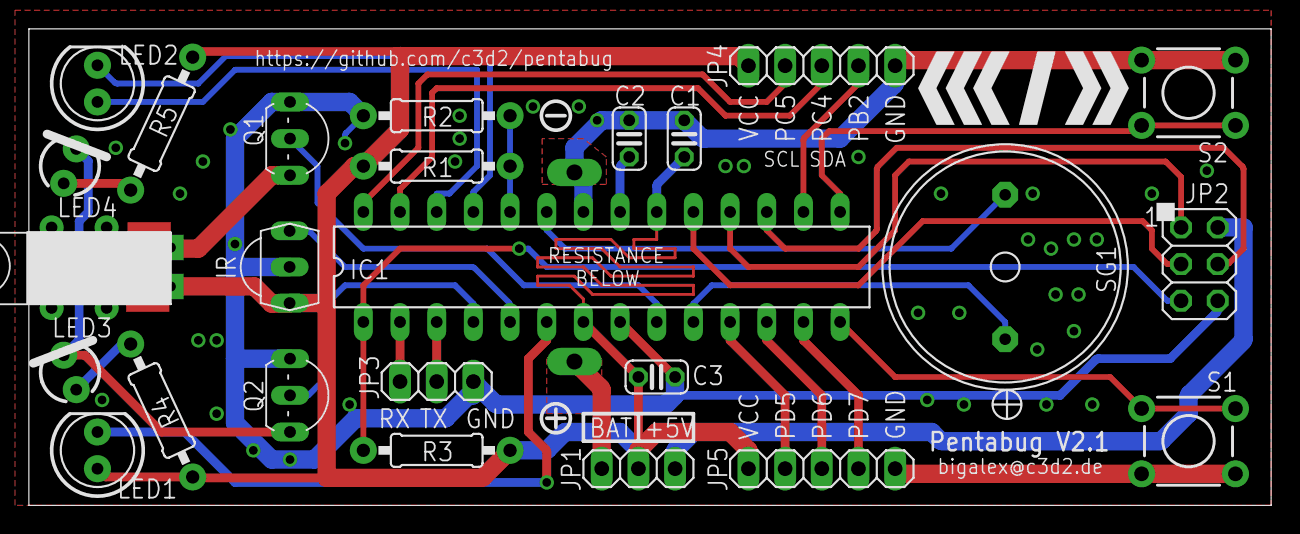
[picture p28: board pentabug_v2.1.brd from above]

Board: 2 copper layers, 86.0 x 33.0 mm, 26 parts (1 on the bottom side), 32 nets.

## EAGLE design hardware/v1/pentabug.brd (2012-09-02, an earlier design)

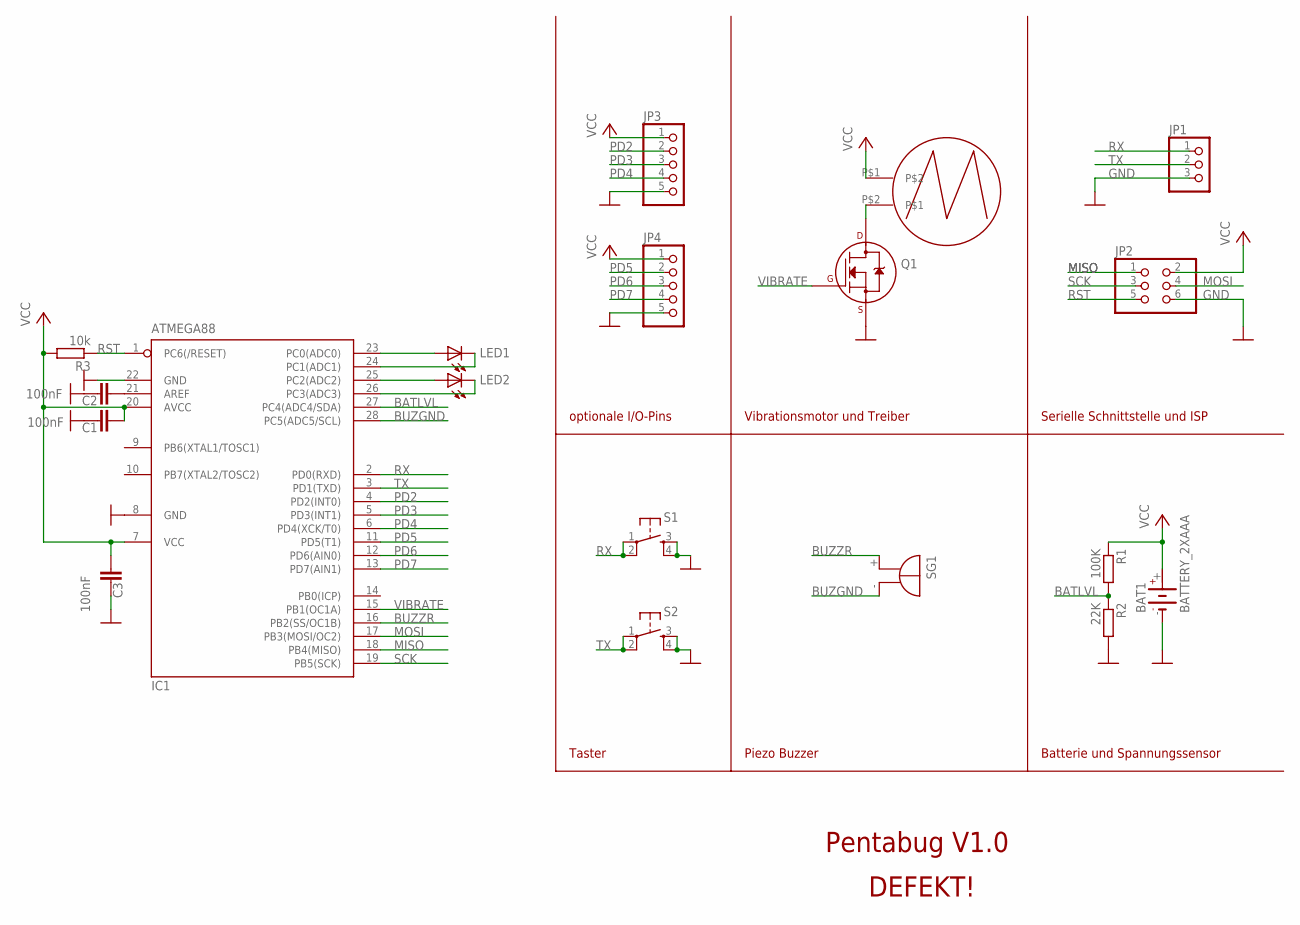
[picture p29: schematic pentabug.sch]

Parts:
BAT1: BATTERY_2XAAA
C1, C2, C3: 100nF; C025-024X044
IC1: ATMEGA88; DIL28-3
JP1: PINHD-1X3; 1X03
JP2: PINHD-2X3; 2X03
JP3, JP4: PINHD-1X5; 1X05
LED1, LED2: LED5MM
Q1: 2N7000_TO92; TO-92
R1: 100K; 0207/10
R2: 22K; 0207/10
R3: 10k; 0207/10
S1, S2: TAC_SWITCHPTH; TACTILE-PTH
SG1: MULTIBUZZRTDKBUZZR; BUZZRTDK
U$1: VIBRAMOTOR; LA4-432

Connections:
BATLVL: IC1.27 (PC4(ADC4/SDA)), R1.2, R2.1
BATTLVL: IC1.26 (PC3(ADC3)), LED2.K (C)
BUZGND: IC1.28 (PC5(ADC5/SCL)), SG1.-
BUZZR: IC1.16 (PB2(SS/OC1B)), SG1.+
GND: BAT1.-, C1.1, C2.1, C3.1, IC1.8 (GND), IC1.22 (GND), JP1.3, JP2.6, JP3.5, JP4.5, Q1.1 (S), R2.2, S1.3, S1.4, S2.3, S2.4
MISO: IC1.18 (PB4(MISO)), JP2.1
MOSI: IC1.17 (PB3(MOSI/OC2)), JP2.4
unnamed: IC1.23 (PC0(ADC0)), LED1.A
unnamed: IC1.25 (PC2(ADC2)), LED2.A
unnamed: Q1.3 (D), U$1.P$2
unnamed: IC1.24 (PC1(ADC1)), LED1.K (C)
unnamed: C2.2, IC1.21 (AREF)
PD2: IC1.4 (PD2(INT0)), JP3.2
PD3: IC1.5 (PD3(INT1)), JP3.3
PD4: IC1.6 (PD4(XCK/T0)), JP3.4
PD5: IC1.11 (PD5(T1)), JP4.2
PD6: IC1.12 (PD6(AIN0)), JP4.3
PD7: IC1.13 (PD7(AIN1)), JP4.4
RST: IC1.1 (PC6(/RESET)), JP2.5, R3.1
RX: IC1.2 (PD0(RXD)), JP1.1, S1.1, S1.2
SCK: IC1.19 (PB5(SCK)), JP2.3
TX: IC1.3 (PD1(TXD)), JP1.2, S2.1, S2.2
VCC: BAT1.+, C1.2, C3.2, IC1.7 (VCC), IC1.20 (AVCC), JP2.2, JP3.1, JP4.1, R1.1, R3.2, U$1.P$1
VIBRATE: IC1.15 (PB1(OC1A)), Q1.2 (G)

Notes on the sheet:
Serielle Schnittstelle und ISP
DEFEKT!
Vibrationsmotor und Treiber
optionale I/O-Pins
Taster
Piezo Buzzer
Batterie und Spannungssensor
Pentabug V1.0

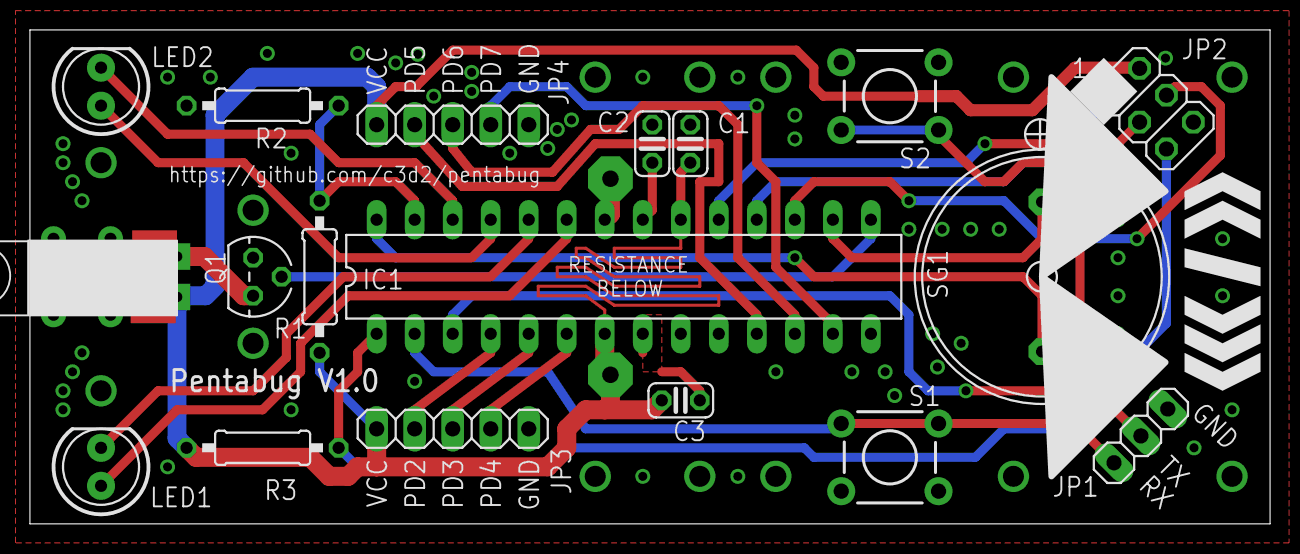
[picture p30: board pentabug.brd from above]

Board: 2 copper layers, 82.9 x 33.0 mm, 19 parts (1 on the bottom side), 24 nets.

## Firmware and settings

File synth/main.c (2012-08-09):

#include <stdlib.h>
#include <stdio.h>
#include <stdint.h>
#include <assert.h>
#include <SDL/SDL.h>

#include "synth.h"


enum { MIXRATE = 8000000 / (6 * 64) };

static SDL_AudioSpec spec = { MIXRATE, AUDIO_U16SYS, 1, 0, 1024, };

static void fill_buffer(void* userdata, Uint8* stream, int len) {
	for(int i = 0; i < len / 2; i++) {
		uint16_t m = synth_mix();
		assert(m < 0x100);
		((uint16_t*)stream)[i] = m * 50;
	}
}

// this parser is a complete hack
// put i can't care less right now

static int wave_counter;
static int inst_counter;
static int pattern_counter;


static int parse_tune(const char* filename) {
	FILE* file = fopen(filename, "r");
	if(!file) return -1;

	wave_counter = 0;
	inst_counter = 0;
	pattern_counter = 0;
	tune_length = 0;

	char wave_names[256][256];
	char inst_names[256][256];
	char pattern_names[256][256];
	memset(wave_names, 0, sizeof(wave_names));
	memset(inst_names, 0, sizeof(inst_names));
	memset(pattern_names, 0, sizeof(pattern_names));


	int state = 0;
	int line_nr = 0;
	char line[256];
	while(fgets(line, 256, file)) {
		line_nr++;

		// skip empty line
		if(line[0] == '\n') continue;

		// comments
		if(line[0] == '#') continue;

		if(state == 0) {
			if(strcmp("[WAVETABLE]\n", line)) return line_nr;
			state = 1;
		}
		else if(state == 1) {
			if(line[0] == '[') {
				if(strcmp("[INSTRUMENTS]\n", line)) return line_nr;
				state = 2;
			}
			else if(!isspace(line[0])) {
				sscanf(line, "%s", wave_names[wave_counter]);
			}
			else if(line[0] == '\t') {
				int a, b;
				if(sscanf(line + 1, "%u %u", &a, &b) != 2) return line_nr;
				wave_table[wave_counter][0] = a;
				wave_table[wave_counter][1] = b;
				wave_counter++;
			}
			else return line_nr;
		}
		else if(state == 2) {
			if(line[0] == '[') {
				if(strcmp("[PATTERNS]\n", line)) return line_nr;
				state = 3;
			}
			else {
				char wave[256];
				int pw, ps, d;
				if(sscanf(line, "%s %u %u %u %s",
					inst_names[inst_counter], &pw, &ps, &d,
					wave) != 5) return line_nr;

				instruments[inst_counter].pulse_width = pw;
				instruments[inst_counter].pulse_sweep = ps;
				instruments[inst_counter].decay = d;
				int i;
				for(i = 0; i < 256; i++)
					if(strcmp(wave_names[i], wave) == 0) break;
				if(i == 256) return line_nr;
				instruments[inst_counter].wave_table_pos = i;
				inst_counter++;
			}
		}
		else if(state == 3) {
			if(line[0] == '[') {
				if(strcmp("[PATTERNTABLE]\n", line)) return line_nr;
				state = 4;
			}
			else {
				if(isspace(line[0])) return line_nr;
				sscanf(line, "%s", pattern_names[pattern_counter]);
				for(int i = 0; i < pattern_length && fgets(line, 256, file); i++) {
					line_nr++;
					if(line[0] != '\t') return line_nr;
					char note[256];
					char inst[256];
					int m = sscanf(line + 1, "%s %s", note, inst);
					if(m == 0) return line_nr;
					char* s = "ccddeffggaab";
					char* p = strchr(s, line[1]);
					if(p) {
						patterns[pattern_counter][i][0] = (p - s) +
								(note[1] == '#') + (note[2] - '0') * 12;
						int j;
						for(j = 0; j < 256; j++)
							if(strcmp(inst_names[j], inst) == 0) break;
						if(j == 256) return line_nr;
						patterns[pattern_counter][i][1] = j;

					}
					else if(m == 1) {
						if(strcmp("---", note) == 0)
							patterns[pattern_counter][i][0] = 0xff;
						else if(strcmp(".", note) == 0)
							patterns[pattern_counter][i][0] = 0;
						else return line_nr;

					}
					else return line_nr;

				}
				pattern_counter++;
			}



		}
		else {
			char* p = line;
			char pat[256];
			for(int i = 0; i < channel_count; i ++) {
				sscanf(p, "%s", pat);
				int j;
				for(j = 0; j < 256; j++)
					if(strcmp(pattern_names[j], pat) == 0) break;
				if(j == 256) return line_nr;
				pattern_table[tune_length][i] = j;
				while(*p && !isspace(*p)) p++;
				while(*p && isspace(*p)) p++;
			}
			tune_length++;


		}
	}
	if(state =! 4) return line_nr;

	fclose(file);

	return 0;
}


static int export_tune(const char* filename) {
	FILE* file = fopen(filename, "w");
	if(!file) return -1;

	fprintf(file, "uint8_t wave_table[][2] = {\n");
	for(int i = 0; i < wave_counter; i++) {
		fprintf(file, "\t{ %d, %d },\n", wave_table[i][0], wave_table[i][1]);
	}
	fprintf(file, "};\n\n");

	fprintf(file, "synth_instrument_t instruments[] = {\n");
	for(int i = 0; i < inst_counter; i++) {
		fprintf(file, "\t{ %d, %d, %d, %d },\n",
			instruments[i].pulse_width,
			instruments[i].pulse_sweep,
			instruments[i].decay,
			instruments[i].wave_table_pos);
	}
	fprintf(file, "};\n\n");

	fprintf(file, "uint8_t patterns[][pattern_length][2] = {\n");
	for(int i = 0; i < pattern_counter; i++) {
		fprintf(file, "\t{\n");
		for(int j = 0; j < pattern_length; j++) {
			fprintf(file, "\t\t{ %d, %d },\n", patterns[i][j][0], patterns[i][j][1]);
		}
		fprintf(file, "\t},\n");
	}
	fprintf(file, "};\n\n");

	fprintf(file, "uint8_t pattern_table[][channel_count] = {\n");
	for(int i = 0; i < tune_length; i++) {
		fprintf(file, "\t{ ");
		for(int j = 0; j < channel_count; j++) {
			fprintf(file, "%d ", pattern_table[i][j]);
		}
		fprintf(file, "},\n");
	}
	fprintf(file, "};\n\n");
	fprintf(file, "enum { pattern_table_length = %d };\n", tune_length);
	fclose(file);

	int size = wave_counter * 2 +
		inst_counter * sizeof(synth_instrument_t) +
		pattern_counter * pattern_length * 2 +
		tune_length * channel_count;
	printf("tune size: %d bytes\n", size);

	return 0;
}


int main(int argc, char** argv) {
	if(argc != 2) {
		printf("usage: %s tunefile\n", argv[0]);
		return 0;
	}

	puts("parsing...");
	int error = parse_tune(argv[1]);
	if(error != 0) {
		fprintf(stderr, "%d: parsing error\n", error);
		return 1;
	}
	puts("exporting...");
	export_tune("tune.h");


	spec.callback = &fill_buffer;
	if(SDL_OpenAudio(&spec, &spec) < 0) {
		fprintf(stderr, "ERROR");
		exit(1);
	}

	SDL_PauseAudio(0);
	puts("playing...");

	getchar();

	return 0;
}

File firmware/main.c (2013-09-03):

#include <setjmp.h>
#include <stdint.h>
#include <stdlib.h>

#include <pentabug/hal.h>
#include <pentabug/app.h>
#include <pentabug/lifecycle.h>
#include <pentabug/music.h>
#include <pentabug/helper.h>

static uint16_t up_mldy[] = { NOTE_C, NOTE_E, NOTE_G, MLDY_LENGTH, 2, NOTE_C/2, NOTE_PAUSE };
static uint16_t down_mldy[] = { NOTE_C/2, NOTE_G, NOTE_E, MLDY_LENGTH, 2, NOTE_C, NOTE_PAUSE };

static inline void run_app(struct app_t* app) {
	app_should_stop = 0;

	if(setjmp(app_jmp_buf) == 0) {
		// initial call

		if(app->init) {
			app->init();
		}

		for(;;) {
			app->run();
			test_stop_app();
		}
	}

	// returned after longjmp()

	if(app->cleanup) {
		app->cleanup();
	}

	return;
}

int main(void) {
	uint8_t app_index = 0;

	init_hw();

	// cycle through apps

	for(;;) {
		reset_hw();

		run_app(&apps[app_index]);

		reset_hw();

		if(app_direction > 0) {
			play_melody(up_mldy, ARRAY_SIZE(up_mldy), 4, 100);

			app_index++;

			if(apps[app_index].run == NULL) {
				app_index = 0;
			}
		} else {
			play_melody(down_mldy, ARRAY_SIZE(down_mldy), 4, 100);

			if(app_index == 0) {
				app_index = MAX_APPS - 1;
				while(apps[app_index].run == NULL) --app_index;
			} else {
				app_index--;
			}
		}
	}
}

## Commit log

2012-06-14 genesis, reusing pentalight
    [pentabug.brd, pentabug.sch]
2012-07-03 initialer neuanfang board
    [pentabug.brd, pentabug.sch]
2012-07-03 changed minimal stuff
    [pentabug.brd]
2012-07-03 buzzer, motor, transistor added
    [pentabug.brd, pentabug.sch]
2012-07-16 alle bauteile prototypmäßig eingesetzt
    [pentabug.brd, pentabug.sch]
2012-07-16 bom initialized...
    still double buzzer...
2012-07-17 Buzzr connected to OC1B, motr driven against Vcc instead gnd
    [pentabug.brd, pentabug.sch]
2012-07-24 adder real used mötör in special lib
    [pentabug.brd, pentabug.sch]
2012-07-24 weiß nich mehr... motor pwm stuff
2012-07-24 Completed with no bugs...
    [main.c]
2012-07-25 added timer0 isr and init
2012-07-29 updated schematics and board to Eagle 6
    [pentabug.brd, pentabug.sch]
2012-07-30 added battery holder, bord layout changed to reflect later constellation of components
    [pentabug.brd, pentabug.sch]
2012-07-30 centered motor package, switched motor pins for convienence
2012-07-30 some routing, buzzer footprint still wrong
    [pentabug.brd, pentabug.sch]
2012-07-30 pulled minor changes in battery holder
    [pentabug.brd, pentabug.sch]
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2012-08-03 some more routing, added new buzzr footprint
    [pentabug.brd]
2012-08-03 some routing
    [pentabug.brd, pentabug.sch]
2012-08-05 changed make flash for serial bootlader to make serflash, changed make flash to support usbtiny isp programmer, set fuses to correct values (default, no brownout, but internal to 8 MHz insted of 1/8 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
2012-08-05 base frequency of pwm lowered
2012-08-06 all sample and legacy code thrown out of main
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2012-08-08 tune file reader (not working/done yet)
    [main.c, synth.h]
2012-08-09 print out tune size
2012-08-11 Enabling timer 2 for LED testing
2012-08-11 Some code for measuring brightness, but not working yet
    [main.c]
2012-08-12 Lots of routing done, GND from Buzzer connected to ADC6 for measurement
    [pentabug.brd, pentabug.sch]
2012-08-12 Started routing for single layer board
    [pentabug_1layer.brd, pentabug_1layer.sch]
2012-08-13 cleaned up and draw power lines
    [pentabug_1layer.brd]
2012-08-13 made editable with eagle freeware!!
    [pentabug_1layer.brd]
2012-08-13 close to final - mass remaining
    [pentabug_1layer.brd]
2012-08-13 implemented timeslot queue to fix #2 but sound is still a bit strange
    [main.c, synth.h]
2012-08-13 final 0.1
    [pentabug_1layer.brd]
2012-08-14 some synth --- sync
    [pentabug_1layer.brd]
2012-08-14 8bitalized synth output stage 1
2012-08-14 some routin
    [pentabug.brd, pentabug_1layer.brd]
2012-08-17 stil not satisfied with routing for 1 layer board
    [pentabug_1layer.brd]
2012-08-19 routing finished
    [pentabug_1layer.brd, pentabug_1layer.sch]
2012-08-21 modified to use biggr buzzr - routing not adapted yet!
    [pentabug.brd, pentabug.sch, pentabug_1layer.brd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]
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2012-08-26 major routing improvents, placement und info prints
    [pentabug.brd]
2012-08-27 replaced mounting holes with big vias
    [pentabug.brd]
2012-08-27 minor fix
    [pentabug.brd]
2012-08-27 bad bug fixed: removed cutout for vibra motor
    [pentabug.brd, pentabug.sch]
2012-08-28 fixed bad bad evil vias connecting Vcc and GND
    [pentabug.brd]
2012-08-28 c3 closer to uC, "resistor" between avcc and vcc
    [pentabug.brd]
2012-08-28 better connection for AVcc block capacitor, Moar vias FTW!
    [pentabug.brd]
2012-08-29 moved vias away from print for LED2
    [pentabug.brd]
2012-09-02 some schematics beautification
    [pentabug.brd, pentabug.sch]
2012-09-02 added schematics to description
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2012-09-24 fixed several errors, added keystuff
    [main.c]
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2012-10-01 switch_l and switch_r in bughal work now
    [main.c]
2012-10-01 demo for direct switch testing, led and motor control
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2012-10-03 some sound with music notes and mode switching
2012-10-05 better sond measurment, tolerant to static voltage on piezo
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2012-10-05 rattling and beeping when detecting sound
    [main.c]
2012-10-05 enable/disable sound and motot by switch in sound detection mode
2012-10-07 more coments and fixed a bug in crazymoves-mode
    [main.c]
2012-10-08 just measuring fotovoltage witch adc works (with vcc as ref)
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2012-10-10 fixed init/deinit inconsitency for mode switching
    [main.c]
2012-10-10 prepared powerdown mode. implement switch combo, blink feedback and signal tone for powerdown interaction
2012-10-11 pwdown still needs isr to wakeup.
    put untested pdown code. please add pinchangeirq
    for either button
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2012-10-11 Revert "Move synth code from lib to app"
    This reverts commit 5dd5bdacaa6fcc6caa0e6b9ca2a81361f76a56e4.
    [crazy_synth.c, main.c]
2012-10-11 Revert "Revert "Move synth code from lib to app""
    This reverts commit d48a6d67d7a0cf14036afc941ecd6f05537cccd6.
    [crazy_synth.c, main.c]
2012-10-11 Fix the freqqing synth table
    [crazy_synth.c]
2012-10-11 coz shorter is always better
    [crazy_synth.c]
2012-10-11 Fix mode switch bug
    [main.c]
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2012-10-12 crazy synth: Initialize buzzer at start
    [crazy_synth.c]
2012-10-12 crazy synth: Fix typo
    [crazy_synth.c]
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2013-03-13 Absolute URL
    Mit absoluter URL werden auch die Bilder angezeigt. ;)
2013-07-06 bug v2 genesis (now with IR!)
    [pentabug_ir.brd, pentabug_ir.sch]
2013-07-07 some beautifications
    [pentabug_ir.brd, pentabug_ir.sch]
2013-07-07 anpassen an neues board
    [ledmatrix.brd, ledmatrix.sch, pentatonic.brd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]
2013-07-07 brauchen wir nicht/doppelt
    [battery-addonnboard.brd, battery-addonnboard.sch, pentatonic-addonnboard.brd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]
2013-07-08 sorted hardware revisions, final production file für the v2 pentabug
    [pentabug.brd, pentabug.sch, pentabug_1layer.brd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]
2013-07-08 delte some older files
    [pentabug.brd, pentabug.sch, pentabug_1layer.brd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]
2013-07-08 Addons are already integrated as own sheet in pentabug v2
    [ledmatrix.brd, ledmatrix.sch, pentatonic.brd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]
2013-07-08 correcting minor glitch (unrouted) in ledmatrix (thanks a lot to the guys from makepcb)
    [finalpanel.brd]
2013-07-13 cost calculation
    [kalkulation.ods]
2013-07-14 moar kalkulation
    [kalkulation.ods]
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2013-08-29 Add high level button code and some documentation
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2013-08-29 Do not attempt to drive the motor with the pullup ...
2013-08-30 fixes issue #6, correct values for r4 and r5
    [pentabug_v2.brd, pentabug_v2.sch]
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2013-08-30 Revert "Save data memory"
    This reverts commit 589275a3ba60d22ac40dd321cf04ef8e06009381.
    [main.c]
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2013-09-04 Move button handling to own timer for better performance
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2013-09-05 Toggle LEDs around playing mario theme (instead of on/off)
2013-09-05 Add missing header to timer
    [timer.h]
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2013-09-05 entwurf einer irempfargstatemachine skizziert....
    sry mehr ging heute einfach nicht mehr.... wir sollten um schnell was zu
    haben mal eine solche kacke runtercoden, und das senden dann
    dementsprechend machen.... ich schlage vor das eine msg immer 2 byte
    lang ist ... sowas wie adresse, keycode ... oder eben einfach eine
    temperatur oder wtf.... jedenfalls feste länge....
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2013-09-20 correct labels in schematic for pentatonic fixes #7
    [pentabug_v2.brd, pentabug_v2.sch]
2013-09-20 correct labels for ledmatrix nets fixes #8
    [pentabug_v2.brd, pentabug_v2.sch]
2013-09-20 marked cathode for IR led3 and led4, fixes #9
    [pentabug_v2.brd]
2014-01-03 started with v2.1 - easy-solder resistors FTW
    [pentabug_v2.1.brd, pentabug_v2.1.sch]
2014-01-03 some improvent on placement of print and mounting holes for motor
    [pentabug_v2.1.brd, pentabug_v2.1.sch]
2014-01-04 I can haz eazy solder transistors.
    [pentabug_v2.1.brd, pentabug_v2.1.sch]
2014-01-08 moar easy soldering
    [pentabug_v2.1.brd]
2014-01-08 some instruction flyers and mekadile changes
    [kalkulation.ods]
2014-08-28 v2.1 production files, updated docs, some cleanup
    [finalpanel.brd, pentabug_v2.1.brd, pentabug_v2.1.sch]
2014-08-28 new order of components
    [kalkulation.ods]
2014-09-01 aufteilung sammelbest.
    [kalkulation.ods]
2014-10-23 doc/de/teil_1:episode_2.md: typo fixed
2014-12-08 ordering parts for 31c3 and some stuff for future projects
    [kalkulation.ods]
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
